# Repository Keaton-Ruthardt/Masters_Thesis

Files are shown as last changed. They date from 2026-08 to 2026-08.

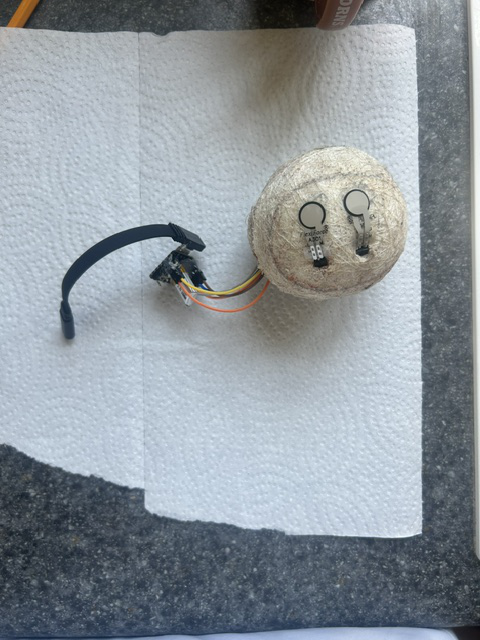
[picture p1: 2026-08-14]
figures/wiring+sensors-stripped-ball.jpeg

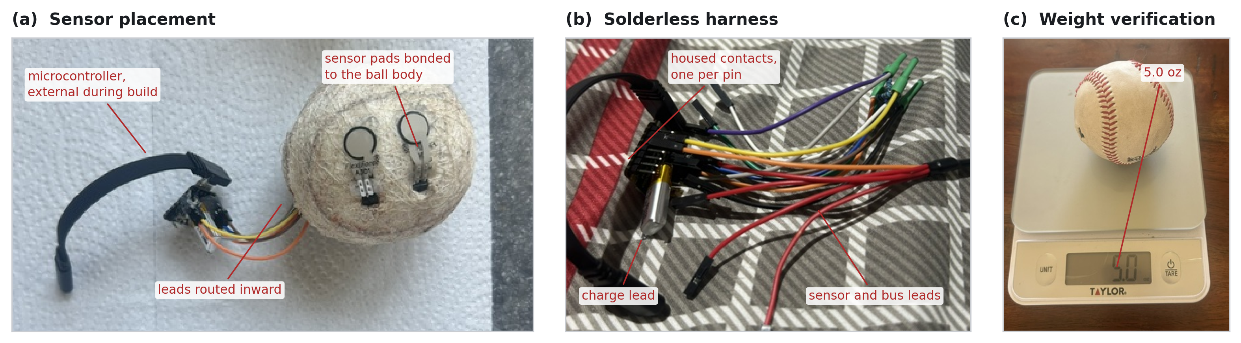
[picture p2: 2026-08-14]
figures/fig3_construction.png

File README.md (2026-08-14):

# An Instrumented Baseball for Per-Finger Grip Force Measurement

Reproducibility materials for the MS thesis *An Instrumented Baseball for Per-Finger
Grip Force Measurement: Finger Force Tracks Delivery Effort Rather Than Release Velocity*
(Keaton Ruthardt, MS Computer Science — Data Science, Oral Roberts University, 2026).

A regulation baseball instrumented with four thin-film force sensors under the leather
cover, sampling all channels at 480 Hz and streaming over Bluetooth Low Energy, paired
per pitch with TrackMan radar release velocity.

## What the study found

Measured the way the field currently measures it — with a graded submaximal effort
ladder — grip force predicts release velocity strongly and broadly: index + middle
force at release reaches *r* = 0.59, and 15 of 20 grip features remain significant
after Holm correction.

Holding commanded effort fixed removes that association. Index + middle force at
release falls to *r* = 0.33 (n.s.), and its unique contribution to velocity variance
is **ΔR² = 0.000**, against 0.743 for commanded effort alone. A mixed-effects model
agrees (χ²(1) = 0.47, *p* = 0.49).

Three thumb-dominated features survive Benjamini–Hochberg correction (*q* = 0.035);
none clears family-wise correction, and all are reported as **exploratory**.

The conclusion is that finger grip force, measured under a submaximal effort protocol,
is largely a readout of delivery effort rather than a determinant of release velocity.

## Layout

| Path | Contents |
|---|---|
| `thesis/` | The thesis (`MSCS_Paper.docx`) and its Quarto source, bibliography, and CSL style |
| `defense/` | Defense presentation, including a copy with speaker notes |
| `Masters_Thesis_and_Defense.zip` | Thesis and presentation bundled together |
| `firmware/` | Arduino sketches for the Seeed XIAO nRF52840 |
| `acquisition/` | `ble_logger.py` — BLE client, writes raw counts to CSV |
| `calibration/` | Per-sensor calibration procedure, fitting script, factors, raw captures |
| `analysis/` | Feature extraction, statistics, and figure generation |
| `analysis/results/` | Derived, de-identified data and generated statistical reports |
| `figures/` | Figures as they appear in the thesis |
| `hardware/` | KiCad PCB project, schematic and layout PDFs, bill of materials |
| `docs/` | Illustrated build guides, project plan, proposal |

### Firmware

- `pressure_logger_480/` — **deployed** acquisition firmware. 480 Hz, four samples per packet.
- `pressure_logger/` — earlier 120 Hz single-sample version; the host logger supports both.
- `isolation_test/` — channel-isolation gate.
- `sensor_test/`, `single_sensor/`, `calibrate_sensors/` — bench-check sketches.

Built with the Arduino IDE and the Seeed nRF52 **mbed-enabled** board package. The
non-mbed package fails to link.

## Wire protocol

The pressure characteristic carries a **36-byte packet**: a 32-bit unsigned microsecond
timestamp for the first sample in the batch, followed by four sample groups of four
16-bit unsigned ADC values each, little-endian, in channel order S1 through S4. Sample
*k* within a batch occurs at the batch timestamp plus *k* × 2083 µs.

The earlier firmware sends a 12-byte packet: a 32-bit millisecond timestamp followed by
four 16-bit ADC values. `ble_logger.py` derives the batch size from the packet length
and works against either version without modification.

## Data dictionary

Each logged CSV row contains:

| Column | Meaning |
|---|---|
| `wall_iso` | Host wall-clock time, ISO 8601, UTC |
| `wall_unix_ms` | Host wall-clock time, integer ms since the Unix epoch |
| `ball_t_ms` | The instrument's own timebase in ms — **the authoritative timing column** |
| `s1`–`s4` | Raw ADC counts, 0–4095, in channel order |
| `s1_N`–`s4_N` | Convenience force values in newtons |
| `marker` | Operator-typed per-pitch tag (pitch id, effort, outcome) |

Raw counts are the archived source of truth. Calibration is applied downstream in
analysis, never on the ball, so it can be revised without re-collecting data.

## Force conversion

For a sensor of resistance *R*ₛ in series with a fixed 10 kΩ resistor, the divider node
read by the 12-bit ADC gives a conductance ratio

```
G = ADC / (4095 - ADC)
F = c * G
```

where *c* is the per-sensor calibration factor in `calibration/calfactors_v3.csv`,
fitted through the origin by least squares over twenty applied-mass trials per sensor
(R² = 0.961 to 0.995).

## Reproducing the analysis

```bash
pip install numpy pandas scipy statsmodels matplotlib
cd analysis
python thesis_analysis_v2.py     # feature extraction -> results/
python advanced_stats.py         # corrections, variance decomposition, bootstrap
python make_thesis_figures.py    # figures
```

A fixed random seed (20260805) makes every reported *p*-value reproducible: 20,000
permutations and 10,000 bootstrap resamples throughout.

Note that `thesis_analysis_v2.py` reads raw session captures, which are not distributed
here (see below). The derived feature table it produces, `analysis/results/per_pitch_features.csv`,
**is** included, and `advanced_stats.py` and `make_thesis_figures.py` run from it directly.

## Participant data

Raw per-pitch session captures are **not included**, in accordance with the
participant-privacy commitments described in the thesis. Participants consented to their
data being used in the study; that consent did not extend to public redistribution of
raw records.

Derived, de-identified summary data sufficient to reproduce the reported figures and
models are provided in `analysis/results/`. Pitchers are identified only as P1, P2, P3.

## Licensing

- **Code and firmware** — [MIT License](LICENSE)
- **Documentation, figures, and build records** — [CC BY 4.0](LICENSE-DOCS)

Both are permissive and allow reuse with attribution, which is the intent for a
reproducibility release: you should be able to rebuild the instrument and re-run the
analysis without seeking further permission.

Third-party software is used in accordance with its own licenses, none of which impose
copyleft obligations on this project's code. TrackMan, PitchLogic, Kookaburra,
FlexiForce, Tekscan, Seeed, and Nordic Semiconductor are trademarks of their respective
owners, used nominatively to identify the products actually used or discussed. No
endorsement is implied.

## Safety

The instrument places a lithium-polymer cell and rigid electronics inside a ball thrown
at speed. If you rebuild it, read `docs/BALL_INTEGRATION_GUIDE.md` first. Epoxy is poured
in ~15 g layers with each cured before the next, because the exotherm of a single large
pour is a genuine thermal hazard to an enclosed LiPo cell, and the cell is wrapped before
potting. The ball is retired — not repaired — if the cover is breached, the potted block
loosens, the cell swells or fails to hold charge, or the channel-isolation test fails
after an impact. The cell cannot be removed once potted, so retirement means disposal of
the whole assembly through appropriate lithium-battery disposal.

## Citation

```bibtex
@mastersthesis{ruthardt2026instrumented,
  author = {Ruthardt, Keaton},
  title  = {An Instrumented Baseball for Per-Finger Grip Force Measurement:
            Finger Force Tracks Delivery Effort Rather Than Release Velocity},
  school = {Oral Roberts University},
  year   = {2026},
  type   = {MS thesis}
}
```

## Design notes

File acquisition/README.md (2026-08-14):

# SmartBall BLE Logger

Streams the XIAO nRF52840 SmartBall's 200 Hz grip-pressure notifications to a
timestamped CSV for post-processing against TrackMan.

Pairs with `firmware/pressure_logger/pressure_logger.ino`.

## Setup

```bash
pip install -r requirements.txt
```

## Run

Power the ball **on the LiPo** (not USB) so it advertises as `SmartBall`, then:

```bash
python ble_logger.py --out session_2026-07-11.csv
```

- Press **ENTER** between pitches to drop a marker row (type a label first, e.g.
  `fastball7`, then ENTER). Use these to align each pitch with its TrackMan row.
- **Ctrl+C** stops cleanly, flushes the file, and prints a summary
  (samples logged, estimated dropped packets, effective rate).

### Options

| Flag | Default | Purpose |
|---|---|---|
| `--out FILE` | `smartball_<timestamp>.csv` | output path |
| `--name NAME` | `SmartBall` | BLE local name to connect to |
| `--duration S` | run until Ctrl+C | auto-stop after S seconds |
| `--scan-timeout S` | `20` | scan timeout before giving up |
| `--no-force` | off | log raw ADC only (skip force columns) |
| `--quiet` | off | suppress the live readout |

## Output columns

`wall_iso, wall_unix_ms, ball_t_ms, idx, mid, thb, rng, idx_N, mid_N, thb_N, rng_N, marker`

- **`ball_t_ms`** — the ball's own `millis()` clock; use this for sample-to-sample
  timing and pitch segmentation.
- **`wall_*`** — laptop wall clock for coarse alignment to TrackMan session time.
- **`idx/mid/thb/rng`** — raw 12-bit ADC. **This is the source of truth.**
- **`*_N`** — convenience force estimate using the firmware conductance model
  (`G = adc/(4095-adc)`, `F = G·calFactor`). `thb`/`rng` calFactors are still
  placeholders (150) pending the S3/S4 calibration fits — re-derive force in
  analysis from raw ADC once those land.

## Notes

- Segment pitches by the grip build-up / release-dropout in the pressure signal,
  cross-checked against the ENTER markers.
- Dropped-packet estimate assumes 5 ms spacing (200 Hz); a `ball_t_ms` jump > 7 ms
  is counted as missed samples. Some loss is expected over BLE — the ball clock
  keeps analysis honest.

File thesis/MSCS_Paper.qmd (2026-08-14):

---
format:
  docx:
    reference-doc: "MSCS Paper Outline.docx"
    toc: false
    number-sections: false
bibliography: references.bib
# APA 7th edition, per reviewer recommendation. To enable: download
#   https://www.zotero.org/styles/apa
# save it as apa.csl beside this file, then uncomment the next line.
# Leaving it commented renders in Chicago author-date (pandoc's default).
csl: apa.csl
---

<!--
  MSCS Paper: Instrumented Baseball for Grip Pressure Analysis
  GCSC 599 — Oral Roberts University
  Author: Keaton Ruthardt

  RENDERING: Run `quarto render MSCS_Paper.qmd` to generate MSCS_Paper.docx

  PRE-SUBMISSION CHECKLIST (Word, after rendering):
  1. Center-align the Title Page and Committee Approval blocks (Ctrl+E)
  2. Right-click the Table of Contents -> Update Field (or Ctrl+A then F9 for all fields).
     Do the same for the List of Tables and List of Figures.
  3. Convert every "Table N." / "Figure N." label to a Word caption via
     References > Insert Caption, so numbering and the lists auto-update.
  4. Accept all tracked changes and turn Track Changes OFF. Remove all comments.
  5. Check page breaks: no heading orphaned at the foot of a page, no table or
     figure split from its caption.
  6. Verify the reference list is alphabetical with hanging indents.
  7. Human proofread. Spelling/grammar tools are a supplement, not a substitute.
-->

```{=openxml}
<w:p><w:pPr><w:jc w:val="center"/></w:pPr><w:r><w:rPr><w:b/></w:rPr><w:t>AN INSTRUMENTED BASEBALL FOR PER-FINGER GRIP FORCE MEASUREMENT: FINGER FORCE TRACKS DELIVERY EFFORT RATHER THAN RELEASE VELOCITY</w:t></w:r></w:p>
<w:p><w:pPr><w:jc w:val="center"/></w:pPr><w:r><w:t></w:t></w:r></w:p>
<w:p><w:pPr><w:jc w:val="center"/></w:pPr><w:r><w:t>A Project</w:t></w:r></w:p>
<w:p><w:pPr><w:jc w:val="center"/></w:pPr><w:r><w:t></w:t></w:r></w:p>
<w:p><w:pPr><w:jc w:val="center"/></w:pPr><w:r><w:t>Presented to</w:t></w:r></w:p>
<w:p><w:pPr><w:jc w:val="center"/></w:pPr><w:r><w:t></w:t></w:r></w:p>
<w:p><w:pPr><w:jc w:val="center"/></w:pPr><w:r><w:t>the Faculty of the Computing and Mathematics Department</w:t></w:r></w:p>
<w:p><w:pPr><w:jc w:val="center"/></w:pPr><w:r><w:t></w:t></w:r></w:p>
<w:p><w:pPr><w:jc w:val="center"/></w:pPr><w:r><w:t>Oral Roberts University</w:t></w:r></w:p>
<w:p><w:pPr><w:jc w:val="center"/></w:pPr><w:r><w:t></w:t></w:r></w:p>
<w:p><w:pPr><w:jc w:val="center"/></w:pPr><w:r><w:t>In partial fulfillment of the requirements for the degree of</w:t></w:r></w:p>
<w:p><w:pPr><w:jc w:val="center"/></w:pPr><w:r><w:t></w:t></w:r></w:p>
<w:p><w:pPr><w:jc w:val="center"/></w:pPr><w:r><w:t>Master of Science, Computer Science, Data Science</w:t></w:r></w:p>
<w:p><w:pPr><w:jc w:val="center"/></w:pPr><w:r><w:t></w:t></w:r></w:p>
<w:p><w:pPr><w:jc w:val="center"/></w:pPr><w:r><w:t>Prepared by</w:t></w:r></w:p>
<w:p><w:pPr><w:jc w:val="center"/></w:pPr><w:r><w:t></w:t></w:r></w:p>
<w:p><w:pPr><w:jc w:val="center"/></w:pPr><w:r><w:rPr><w:i/></w:rPr><w:t>Keaton Ruthardt</w:t></w:r></w:p>
<w:p><w:pPr><w:jc w:val="center"/></w:pPr><w:r><w:t></w:t></w:r></w:p>
<w:p><w:pPr><w:jc w:val="center"/></w:pPr><w:r><w:rPr><w:i/></w:rPr><w:t>August 2026</w:t></w:r></w:p>
<w:p><w:r><w:br w:type="page"/></w:r></w:p>
<w:p><w:pPr><w:jc w:val="center"/></w:pPr><w:r><w:rPr><w:b/></w:rPr><w:t>Committee Approval</w:t></w:r></w:p>
<w:p><w:pPr><w:jc w:val="center"/></w:pPr><w:r><w:t></w:t></w:r></w:p>
<w:p><w:pPr><w:jc w:val="center"/></w:pPr><w:r><w:t>This project report has been reviewed and unanimously approved by the Project Committee.</w:t></w:r></w:p>
<w:p><w:pPr><w:jc w:val="center"/></w:pPr><w:r><w:t></w:t></w:r></w:p>
<w:p><w:pPr><w:jc w:val="center"/></w:pPr><w:r><w:t>____________________________________     ______________________________</w:t></w:r></w:p>
<w:p><w:pPr><w:jc w:val="center"/></w:pPr><w:r><w:t>Dr. Woerner, Committee Chair                Signature and Date</w:t></w:r></w:p>
<w:p><w:pPr><w:jc w:val="center"/></w:pPr><w:r><w:t></w:t></w:r></w:p>
<w:p><w:pPr><w:jc w:val="center"/></w:pPr><w:r><w:t>____________________________________     ______________________________</w:t></w:r></w:p>
<w:p><w:pPr><w:jc w:val="center"/></w:pPr><w:r><w:t>Dr. Valderrama, Committee Member            Signature and Date</w:t></w:r></w:p>
<w:p><w:pPr><w:jc w:val="center"/></w:pPr><w:r><w:t></w:t></w:r></w:p>
<w:p><w:pPr><w:jc w:val="center"/></w:pPr><w:r><w:t>____________________________________     ______________________________</w:t></w:r></w:p>
<w:p><w:pPr><w:jc w:val="center"/></w:pPr><w:r><w:t>Wes Davis, Committee Member                 Signature and Date</w:t></w:r></w:p>
<w:p><w:r><w:br w:type="page"/></w:r></w:p>
```

```{=openxml}
<w:p>
  <w:pPr><w:jc w:val="center"/></w:pPr>
  <w:r>
    <w:rPr><w:b/></w:rPr>
    <w:t>Table of Contents</w:t>
  </w:r>
</w:p>
<w:p>
  <w:r>
    <w:fldChar w:fldCharType="begin" w:dirty="true"/>
  </w:r>
  <w:r>
    <w:instrText xml:space="preserve"> TOC \o "1-1" \h \z \u </w:instrText>
  </w:r>
  <w:r>
    <w:fldChar w:fldCharType="separate"/>
  </w:r>
  <w:r>
    <w:t>[Right-click and select Update Field to generate the Table of Contents]</w:t>
  </w:r>
  <w:r>
    <w:fldChar w:fldCharType="end"/>
  </w:r>
</w:p>
<w:p><w:r><w:br w:type="page"/></w:r></w:p>
<w:p><w:pPr><w:jc w:val="center"/></w:pPr><w:r><w:rPr><w:b/></w:rPr><w:t>List of Tables</w:t></w:r></w:p>
<w:p>
  <w:r><w:fldChar w:fldCharType="begin" w:dirty="true"/></w:r>
  <w:r><w:instrText xml:space="preserve"> TOC \h \z \t "Table Caption,1" </w:instrText></w:r>
  <w:r><w:fldChar w:fldCharType="separate"/></w:r>
  <w:r><w:t>[Right-click and select Update Field to generate the List of Tables]</w:t></w:r>
  <w:r><w:fldChar w:fldCharType="end"/></w:r>
</w:p>
<w:p><w:pPr><w:jc w:val="center"/></w:pPr><w:r><w:rPr><w:b/></w:rPr><w:t>List of Figures</w:t></w:r></w:p>
<w:p>
  <w:r><w:fldChar w:fldCharType="begin" w:dirty="true"/></w:r>
  <w:r><w:instrText xml:space="preserve"> TOC \h \z \t "Figure Caption,1" </w:instrText></w:r>
  <w:r><w:fldChar w:fldCharType="separate"/></w:r>
  <w:r><w:t>[Right-click and select Update Field to generate the List of Figures]</w:t></w:r>
  <w:r><w:fldChar w:fldCharType="end"/></w:r>
</w:p>
```

{{< pagebreak >}}

# PROJECT DESCRIPTION

This project presents the design and construction of an instrumented baseball that measures grip pressure distribution at the finger contact points during live pitching. The instrument embeds four thin-film force-sensitive resistors at the primary finger contact points (index, middle, thumb, and ring finger), sampled by a Bluetooth Low Energy 5 microcontroller (Seeed XIAO nRF52840) that streams the data wirelessly to a companion logger. Release velocity is captured concurrently by an Oral Roberts University TrackMan Doppler radar system, an established commercial pitch-tracking reference that has been reported as the ball-tracking component of Major League Baseball's Statcast system [@trackman; @statcast]. Each pitch therefore yields a paired record: how the ball was gripped, measured on-board, and what the ball did as a result, measured independently. Sourcing the ball-flight outcome externally rather than from on-board inertial sensors lets the instrument concentrate on the grip-pressure measurement it uniquely provides. The complete assembly preserves regulation weight and balance.

The specific contribution is the combined measurement system: per-pitch, per-finger grip behavior recorded through the release event, paired with independently measured ball-flight outcomes. Prior instrumented baseballs have measured either finger force or ball flight; the reviewed literature does not report a system that records both for the same pitch at four finger positions [@kinoshita2017; @yeh2024; @pitchlogic].

## Problem Statement

Pitch-tracking systems measure what the ball does after it leaves the pitcher's hand, and none of them measures the grip that produced it [@pitchlogic; @statcast]. Research instruments that do measure finger force during pitching exist, but they are laboratory devices that report force alone, and the most recent instrumented only the index and middle fingers [@kinoshita2017; @yeh2024]. A pitcher told to change how they hold the ball therefore has no way to verify that the change was executed, and no way to relate it to the result.

That is a measurement gap, and closing it is the primary engineering problem this project addresses. But there is a second problem, in the evidence rather than the instrumentation, and it turns out to govern what the measurement is worth.

Establishing that grip force relates to release velocity *within* a pitcher requires a spread of velocities to correlate against. A single pitcher's maximum-effort fastballs vary by little more than the resolution of the outcome instrument, so the standard solution is a graded submaximal effort protocol [@kinoshita2017]. Commanded effort, however, raises grip force and ball velocity together. A correlation obtained under that protocol is confounded by the very design that made it estimable, and it cannot by itself distinguish a genuine grip--outcome relationship from the trivial observation that harder throws involve harder gripping. Separating the two requires recording commanded effort for every pitch and holding it fixed in the analysis --- which in turn requires an instrument that captures per-finger grip force pitch by pitch, under live conditions rather than in a laboratory.

This project therefore addresses two coupled problems: it builds a self-contained instrumented baseball that records grip pressure at four finger positions during live pitching, pairs each pitch with an independently measured release velocity, and uses that pairing to test whether grip force carries velocity information that delivery effort does not.

## Scope and Deliverables

The project is organized into five phases:

1. **Proof of Concept** (Weeks 1--4): Breadboard prototype with pressure sensors, a development-grade IMU, and BLE data transmission to validate the core data pipeline.
2. **nRF52840 Migration and Four-Sensor Array** (Weeks 5--10): Migration from ESP32 to the nRF52840 microcontroller, the platform adopted by comparable commercial smart balls, expansion to four pressure sensors covering the primary finger positions, and firmware rewrite for BLE 5.
3. **Instrument Fabrication** (Weeks 11--16): Building a throwable, self-contained instrument around the Seeed XIAO nRF52840, a lithium-polymer battery, and the four-sensor array, with per-sensor force calibration. A custom rigid PCB was attempted during this phase; its fabrication outcome and the resulting build decision are documented in the milestones and change proposals.
4. **Baseball Integration** (Weeks 17--19): Embedding the electronics into a regulation baseball using a construction method informed by McGinnis (2012) and Yeh et al. (2024), routing sensor leads to the finger contact positions, and verifying weight, balance, and durability for live throwing.
5. **Data Collection and Analysis** (Weeks 20--26): Capturing paired grip-pressure and TrackMan ball-flight data across pitchers and pitch types, and developing a companion pipeline that extracts grip-force features and relates them to release velocity.

## Equipment and Facilities

**Fabrication and bench equipment.** Soldering station, digital multimeter, breadboards, and a crimping tool for the insulated ferrule and housed-contact terminations used in the second instrument. A digital scale reading to 0.1 g verifies regulation mass, and a flat roll surface checks balance.

**Deployed instrument.** Four FlexiForce A301 thin-film force sensors; a Seeed XIAO nRF52840 development board (Nordic Semiconductor nRF52840 with BLE 5); a 100 mAh lithium-polymer cell charged through the board's on-board charger via a USB-C pigtail; 10 k$\Omega$ divider resistors; two-part epoxy for potting; and a regulation baseball, deconstructed and re-stitched. The custom printed circuit board specified in the original plan was fabricated but non-functional, and the deployed instrument is built on the development board instead (CP-12).

**Calibration.** Per-sensor calibration was performed against a scale-referenced staircase of known masses applied through a rigid platen, twenty trials per sensor, with the fitted factors recorded in Table 1 and applied downstream in analysis rather than on the ball.

**Ball-flight reference.** Release velocity is obtained from the Oral Roberts University TrackMan Doppler radar, a stadium-grade commercial tracking system [@trackman; @statcast]. TrackMan also reports spin and movement, but Doppler tracking of the instrumented ball proved intermittent---the altered interior shortens the radar track---and those quantities were recovered for too few pitches to analyze. **Velocity is the only ball-flight outcome used in this work.**

**Facilities.** Data collection took place at the ORU TrackMan facility, throwing from a mound at regulation distance during ordinary training sessions.

**Software.** A companion Python logger built on the Bleak Bluetooth library records the wireless stream to timestamped CSV, with each pitch's outcome typed into a marker field at capture. Analysis is in Python (NumPy, pandas, SciPy, statsmodels, scikit-learn, Matplotlib).

Actual expenditure is reported per phase in the milestones rather than estimated here.

## Subject Matter Experts

The project committee consists of Dr. Woerner (Chair), Dr. Valderrama, and Wes Davis, who provide expertise in computer science, data science, and domain knowledge relevant to the project.

## Project Criteria

This project satisfies the criteria for a master's project as follows:

- **Independence.** The project is a discrete unit with a well-defined beginning (sensor validation) and end (a functioning instrumented baseball with analysis capability), with clearly defined success criteria at each phase.
- **Ownership.** The student is solely responsible for all hardware design, firmware development, integration, and analysis pipeline development.
- **Background Research.** The project requires investigation of prior instrumented ball designs, force-sensing technologies, embedded systems packaging constraints, and pitching biomechanics literature before and during implementation.
- **Creativity.** Within the products and literature reviewed for this project, no existing design combines multi-point grip-pressure sensing with a concurrent, independently measured ball-flight outcome in a single baseball-form-factor instrument. The solution requires integration of mechanical, electrical, and software engineering disciplines.

# MOTIVATION

Modern pitch-tracking technologies have advanced rapidly in quantifying ball-flight metrics. Products such as PitchLogic embed inertial sensors inside a regulation baseball to report velocity, spin rate, spin axis, and seam orientation in near-real-time [@pitchlogic]. Radar- and camera-based systems such as Rapsodo [@driveline2018], and stadium-level installations such as Statcast [@statcast], provide additional ball-flight data from external vantage points. However, all of these systems measure only what the ball does after it leaves the pitcher's hand; they capture no information about the grip forces that produced those outcomes.

This gap matters because recent biomechanics research demonstrates a direct link between finger forces and pitch quality. A 2024 study published in *Sensors* used a sensor-embedded baseball to examine finger characteristics in twenty-one pitchers and found significant correlations between finger force rate of development, impulse, and force discrepancy with both spin rate and pitching velocity [@yeh2024]. Earlier work by Kinoshita et al. established that the index and middle fingers each exert peak resultant forces of approximately 97 N during fastball delivery, and that the shear forces generated by these fingers at release---summing to 102 N---are the kinetic source of backspin [@kinoshita2017]. These studies provide evidence that grip force patterns are not merely incidental to pitching mechanics.

There is, however, a difficulty in that evidence that motivates the present work as much as the measurement gap does. Establishing a within-pitcher relationship between grip force and velocity requires a range of velocities to correlate against, and the standard way to induce that range is to have the pitcher throw at graded submaximal effort [@kinoshita2017]. But commanded effort raises grip force and ball velocity together, so a correlation obtained that way is confounded by the design that made it estimable. Distinguishing a grip--outcome relationship from the trivial observation that harder throws involve harder gripping requires recording commanded effort per pitch and holding it fixed---which requires, in turn, an instrument that captures grip force pitch by pitch under live conditions. That is the instrument this project builds, and the distinction turns out to matter a great deal.

Despite this evidence, no existing tool provides pitchers or coaches with objective, real-time feedback on grip pressure distribution during live throws. Training adjustments remain guided by subjective feel and verbal coaching cues. A pitcher who is told to "grip the ball tighter with the index finger" has no way to quantify that adjustment or verify that it was executed as intended. This leaves a critical performance variable unmeasured and unmanaged.

The instrumented baseball developed in this project addresses that gap. By embedding force-sensitive resistors at each finger contact point and pairing them with a concurrent, independently measured release velocity, the system produces a unified per-pitch dataset: how the ball was gripped and what the ball did as a result. This pairing supports a feedback loop that subjective coaching cues alone cannot provide.

The platform may also be relevant to training-load research. Pitching biomechanics research has quantified the substantial elbow and shoulder loads the throwing motion generates and connected them to injury mechanisms [@fleisig1995], and Kinoshita et al. observed that maximal-effort fastballs demand more than 80 percent of a pitcher's measured maximum finger strength, which the authors interpret as supporting a role for distal-finger conditioning [@kinoshita2017]. Whether measured finger-force patterns carry any predictive relationship to injury is beyond the scope and design of the present study, and no such claim is made here; the connection is identified only as a direction that a larger prospective study could investigate. The architecture is generalizable to other sports where grip is consequential and unmeasured, including cricket bowling, softball pitching, and football throwing.

# OBJECTIVES

The primary objective is to design and fabricate a throwable, self-contained instrumented baseball that captures real-time grip pressure distribution across four finger contact points (index, middle, thumb, and ring finger) during regulation pitching motions. The instrument embeds four thin-film force-sensitive resistors at the finger contact positions, samples all four channels continuously, and transmits the resulting data wirelessly via Bluetooth Low Energy 5 to a companion logger. The complete assembly maintains regulation weight and balance.

The secondary objective is to pair each pitch's grip-pressure record with independently measured ball-flight outcomes. Rather than estimating velocity and spin from on-board inertial sensors---an approach constrained by MEMS gyroscope saturation and by drift in the integration of accelerometer data---this project uses the Oral Roberts University TrackMan Doppler radar as the ball-flight reference, providing release velocity for every pitch it successfully tracks. Individual pitches are tagged during capture and joined to their TrackMan records, producing a unified per-pitch dataset. Release is delimited within the pressure signal itself by the characteristic build-up and drop-out of grip force.

A tertiary objective is to develop a companion data pipeline that ingests the paired datasets and extracts interpretable grip-force features---peak force, rate of force development, impulse, and inter-finger force balance---for each pitch, then relates those features to release velocity. The analysis focuses on two representative pitch types, the four-seam fastball and the curveball, which contrast a low-movement, high-velocity grip with a high-spin, breaking-ball grip. The pipeline includes pitch segmentation, calibrated force conversion, feature extraction, and exploratory statistical analysis in Python, with data exported in standard formats (CSV).

# BACKGROUND: PRIOR AND OTHER CURRENT WORK

The study of pitching biomechanics has a long history, but instrumented measurement of the finger-ball interface remains in its early stages. This section reviews the key prior work that informs the present project, spanning commercial products, academic research on instrumented baseballs, and biomechanical studies of finger forces during pitching.

## Commercial Products: PitchLogic

PitchLogic represents the current state of the art in consumer-grade instrumented baseballs. The product embeds an inertial measurement unit inside a regulation-weight baseball and uses Bluetooth Low Energy to transmit pitch data to a companion mobile application in less than 0.1 seconds after release [@pitchlogic]. Reported metrics include velocity, spin rate, spin axis, spin efficiency, seam orientation, and release point. Pitching-development facilities such as Driveline Baseball have evaluated smart-ball and pitch-tracking technologies for training feedback [@driveline2018]. PitchLogic demonstrates the viability of embedding electronics in a baseball while maintaining acceptable weight and balance, and it validates BLE as a practical wireless protocol for this application. However, PitchLogic measures only ball-flight dynamics; it includes no pressure sensors and provides no information about grip forces.

## Miniaturized IMU Design for Baseballs

McGinnis and Perkins developed a highly miniaturized wireless IMU specifically designed for embedding in pitched baseballs and softballs [@mcginnis2012]. Their work established several important design principles for instrumented balls. First, the electronics must be centered at the ball's center of mass to minimize perturbation of the ball's moments of inertia. Second, the total added mass must be minimized---their design targeted masses small enough to avoid detectable changes in ball dynamics. Third, the IMU must have sufficient gyroscope range and sampling rate to capture the high angular velocities encountered in pitching, where fastball spin rates typically range from roughly 1,800 to 2,800 RPM [@statcast]. Their validation work confirmed that a properly miniaturized and centered electronics package does not significantly alter the flight characteristics of the ball, providing a critical proof of concept for the present project's approach to embedding additional pressure-sensing hardware.

## Finger Forces in Pitching

Kinoshita et al. conducted a foundational study of finger forces during fastball pitching by installing a three-dimensional force transducer inside a baseball [@kinoshita2017]. Data collected from eleven pitchers revealed that the index and middle fingers exhibit a bimodal force pattern, with initial peaks at approximately 38--39 milliseconds before release and secondary peaks at 6--7 milliseconds before release, each reaching approximately 97 N. The ring finger and thumb produced single-peak forces of approximately 50 N and 83 N, respectively. The shear forces generated by the index and middle fingers formed distinct peaks at 4--5 milliseconds before release, summing to 102 N---identified as the primary kinetic source of backspin. An additional experiment with submaximal effort demonstrated a linear relationship between peak finger forces and ball velocity, and the peak forces during maximal-effort fastballs exceeded 80 percent of measured maximum finger strength, suggesting that distal finger strengthening is important for both performance enhancement and injury prevention.

## Sensor-Embedded Baseball for Finger Characteristics

Most recently, Yeh et al. designed a sensor-embedded baseball to investigate the relationship between finger characteristics and pitching performance [@yeh2024]. Their study of twenty-one pitchers measured finger length and strength alongside pitch metrics captured by the embedded sensors. They found significant correlations between finger force rate of development, impulse, and inter-finger force discrepancy with both spin rate and pitching velocity. This work is the closest precursor to the present project in that it combines force measurement with ball-embedded sensing, though it focused on static finger characteristics rather than dynamic, pitch-by-pitch pressure distribution mapping.

## Related Instrumented-Ball and Sensing Systems

Instrumenting sports balls with embedded electronics is an established line of work beyond baseball. Miniature wireless inertial units have characterized golf-swing dynamics [@king2008] and bowling-ball motion [@king2011], and smart cricket balls have been developed for detailed bowling performance analysis [@fuss2015; @fuss2021]. Distributed wearable sensor systems have likewise been applied to evaluating pitchers and batters [@paradiso2006], and the instrumented-baseball concept has been patented [@perkins_patent2015; @mcginnis_procedia2012]. The Nordic nRF52840 microcontroller used here is the same platform adopted by commercial smart balls, including the Kookaburra SmartBall [@nordic_smartball] and the PitchLogic baseball [@nordic_pitchlogic; @nordic_nrf52840], and independent validation of PitchLogic against reference instruments has been reported [@samford2020; @driveline2018]. On the sensing side, the FlexiForce A301 force-sensitive resistor is a widely used thin-film transducer whose conductance-versus-force behavior underlies the calibration model applied in this project [@tekscan_a301]. For ball-flight interpretation, spin and movement follow well-characterized baseball aerodynamics [@nathan_aero], and magnetometer-based spin measurement---the commercial basis for treating spin as an externally measured quantity---has been described in the patent literature [@diamondkinetics_spin].

## Synthesis

Collectively, these studies establish three key findings that motivate the present project: (1) finger forces are directly linked to pitch quality and can be measured with embedded sensors; (2) electronics can be embedded in a baseball without significantly altering its dynamics; and (3) no existing system provides per-pitch grip pressure distribution data paired with a concurrent ball-flight outcome. The present project addresses this gap by combining multi-point grip-pressure sensing with a concurrent, externally referenced release velocity in a single, wirelessly communicating instrument.

# REQUIREMENTS (project)

This section specifies the functional and non-functional requirements for the instrumented baseball system.

## Functional Requirements

The system shall:

1. **Measure grip pressure** at four discrete finger contact points (index, middle, thumb, and ring finger) using thin-film force-sensitive resistors [@tekscan_a301]. Each sensor resolves forces across the 0--25 pound (0--111 N) range with sufficient resolution to distinguish meaningful grip adjustments.

2. **Sample all four pressure channels** continuously at a fixed rate sufficient to resolve the release transient, time-stamped on-board so that grip build-up, peak, and release are temporally resolved within each pitch. The reference literature places the second pre-release force peak 6 to 7 ms before release [@kinoshita2017] and samples at 433 Hz [@yeh2024], establishing a target of at least 400 Hz. The deployed instrument samples at 480 Hz.

3. **Transmit data wirelessly** via Bluetooth Low Energy 5 to a companion logging device, which records the stream to timestamped CSV for post-processing.

4. **Support per-pitch tagging** during capture so that each grip-pressure record can be joined to its corresponding TrackMan ball-flight record.

5. **Delimit release** from the pressure signal itself: grip force builds during the arm action and drops out at ball release, marking the release point and bounding each pitch for feature extraction. Because the channels lose contact at different instants, release is resolved per finger rather than as a single ball-level event.

6. **Maintain channel independence.** Each pressure channel shall respond only to force applied at its own sensor. Cross-channel response shall remain below 5 percent of the driven channel, verified by instrumented test before and after each stage of assembly.

7. **Recharge via a wired USB-C connection.** No exposed high-voltage ports are present on the ball's surface during throwing, and the charge port is reachable for recharging and for firmware updates without disassembling the ball.

## Non-Functional Requirements

1. **Weight.** The total mass of the instrumented baseball shall not exceed 5.25 ounces (148.8 g), the upper bound of the regulation baseball weight of 5 to 5.25 ounces [@mlb_rules]. The added electronics mass shall be below 12 g, with a design target below 8 g.

2. **Balance.** The center of mass of the instrumented baseball shall not deviate perceptibly from that of a standard baseball. All electronics shall be centered at or near the geometric center of the ball.

3. **Sensor profile.** Pressure sensors mounted along the seams shall not exceed 0.5 mm in thickness to avoid perceptible alteration of the ball's grip surface.

4. **Durability.** The system shall withstand repeated pitching at velocities of 80+ mph without sensor or electronics failure. The design shall include potting and structural protection for internal components. *Met:* the deployed instrument was thrown at up to 82.4 mph across three sessions without sensor or electronics failure, streaming continuously and passing the channel-isolation check after use.

5. **Battery life.** The system shall operate on a single charge for the duration of a full data-collection session (several hours). Measured runtime is approximately eight hours on a 100 mAh, 3.7 V cell.

6. **Sampling fidelity.** Analog-to-digital conversion shall provide at least 12-bit resolution across all pressure channels.

7. **Latency.** Grip-pressure samples shall stream continuously to the receiving device in near-real-time over BLE, with the ball's own timestamp on each sample so that timing is preserved even when individual packets are dropped.

# DESIGN SPECIFICATION (project)

This section describes the system architecture, component selection rationale, data flow, power system design, and sensor placement strategy for the instrumented baseball.

## System Architecture

The instrumented baseball comprises three subsystems: (1) a four-channel grip-pressure sensor array, (2) a microcontroller with BLE 5 wireless communication, and (3) a rechargeable power system. Ball-flight metrics are supplied externally by the TrackMan Doppler radar rather than sensed on-board, which removes the inertial-measurement subsystem from the deployed instrument and focuses it on the grip-pressure measurement it is uniquely able to provide. Figure 1 shows the complete signal path.

Block diagram of the instrumented baseball system. On the ball: four FlexiForce A301 sensors feed voltage dividers, sampled by a XIAO nRF52840 at 480 Hz, powered by a 100 mAh cell. Off the ball: a Bluetooth Low Energy link carries raw counts to a Python logger, and TrackMan radar supplies release v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

::: {custom-style="Figure Caption"}
Figure 1. *Instrumented baseball system architecture.* Force applied at each of four finger positions changes the resistance of a thin-film sensor; each sensor forms a voltage divider with a fixed 10 k$\Omega$ resistor, and the divider nodes are sampled by the microcontroller's 12-bit converter at 480 Hz. Samples are buffered, batched four to a packet, and transmitted over Bluetooth Low Energy to a Python logger that writes raw counts to CSV. Release velocity is measured independently and joined to the pressure record by a per-pitch tag. Note that calibration is applied downstream in analysis, not on the ball, so raw counts remain the archived source of truth.
:::

## Pressure Sensor Array

The pressure sensor array consists of four FlexiForce A301 thin-film force-sensitive resistors manufactured by Tekscan [@tekscan_a301]. These sensors are the same transducer family used by Yeh et al. in the closest precursor work, which employed the compact A301 variant of the same 0--111 N sensor [@yeh2024]. These sensors were selected for their ultra-thin polyester construction (0.2 mm thickness), small sensing area (9.5 mm diameter), and measurement range of 0--25 pounds (0--111 N), which encompasses the expected finger forces during pitching [@kinoshita2017]. The sensors are positioned at four finger contact points: one each for the index finger, middle finger, thumb, and ring finger. This configuration samples grip force at four discrete locations rather than mapping a continuous pressure distribution, and it extends the coverage of the closest prior work: Yeh et al. instrumented only the index and middle fingers, reporting no thumb or ring-finger data [@yeh2024]. Following the Yeh et al. construction method, the sensors are placed beneath the leather cover, where the leather transmits finger force to the 0.2 mm sensor while preserving natural grip feel. Figure 3 shows the sensor placement and internal construction.

## Ball-Flight Reference (TrackMan)

Ball flight is not sensed on-board. **Release velocity is the outcome measure of this work**, and it is obtained from the Oral Roberts University TrackMan Doppler radar, a stadium-grade commercial tracking system reported as the ball-tracking component of MLB Statcast [@trackman; @statcast; @nathan_aero]. TrackMan also reports spin rate, spin axis, and movement, and those quantities were recorded wherever the system returned them; in practice the instrumented ball's altered interior produced a shortened, intermittent radar track and they were recovered for too few pitches to support inference. They are reported descriptively where present and enter no model. Every outcome analysis in this document is against velocity. This choice avoids two well-documented limitations of ball-embedded inertial sensing. First, MEMS gyroscopes typically saturate near ±4,000 degrees per second [@st_ism330dhcx]---approximately 666 RPM on a single axis---far below the 1,800 to 2,800 RPM of a competitive fastball [@statcast], so a gyroscope cannot measure real pitch spin without saturating. Second, velocity estimates obtained by integrating accelerometer data accumulate drift. Using TrackMan as the ball-flight reference yields more accurate outcome measurements than an on-board IMU could provide, and lets the instrument devote its entire mass and power budget to grip-pressure sensing.

## Signal Conditioning

The pressure sensors are conductive-polymer force-sensitive resistors whose resistance falls (conductance rises) approximately linearly with applied normal force [@tekscan_a301]. Each sensor forms a voltage divider with a fixed 10 k$\Omega$ resistor, and the four divider nodes connect directly to analog inputs A0 through A3 of the XIAO nRF52840; no multiplexer is required.

For a sensor of resistance $R_s$ in series with the fixed resistor $R_f$, the divider node sampled by the 12-bit analog-to-digital converter reads

$$ \mathrm{ADC} = (2^{12}-1)\,\frac{R_f}{R_s + R_f}, \tag{1} $$

so that the dimensionless ratio

$$ G = \frac{\mathrm{ADC}}{4095 - \mathrm{ADC}} = \frac{R_f}{R_s} \tag{2} $$

is proportional to sensor conductance $1/R_s$. Because conductance is approximately proportional to applied force, force is recovered as

$$ F = c\,G = c\,\frac{\mathrm{ADC}}{4095 - \mathrm{ADC}}. \tag{3} $$

The symbols are defined as follows. $F$ is the applied normal force in newtons (N). $\mathrm{ADC}$ is the raw converter output, a dimensionless integer in the range 0 to 4095 at 12-bit resolution. $R_s$ is the sensor resistance in ohms ($\Omega$), which decreases with applied force. $R_f$ is the fixed divider resistance, 10 k$\Omega$ ($\pm$1 percent, metal film). $G$ is the dimensionless conductance ratio defined in Equation (2). The coefficient $c$ is the per-sensor calibration factor, in newtons per unit conductance ratio (N), determined empirically by the least-squares procedure described in *Sensor Calibration*; it is denoted `calFactor` in the firmware and analysis code.

Equation (3) is fit through the origin, on the physical grounds that zero applied force produces zero conductance. Raw $\mathrm{ADC}$ values are transmitted rather than converted force, so calibration is applied in post-processing and can be revised without re-collecting data. Two additional analog pins (A4, A5) remain unpopulated and available for future sensor expansion.

## Microcontroller and Wireless Communication

The Nordic Semiconductor nRF52840 serves as the central processing unit. This microcontroller was selected because it is the platform used by the closest commercial comparators: PitchLogic reports using the nRF52840 in its smart baseball [@nordic_pitchlogic], and the Kookaburra SmartBall uses it in its cricket ball [@nordic_smartball]. Adopting the same platform reduces technical risk, since the part is demonstrably capable of operating inside a thrown ball. Key specifications include a 64 MHz ARM Cortex-M4F processor with hardware floating-point unit, 256 KB SRAM, 1 MB flash, integrated BLE 5 radio (2 Mbps throughput), six analog input channels, and ultra-low-power sleep modes drawing less than 1 µA in system-off mode [@nordic_nrf52840].

The deployed instrument uses the Seeed XIAO nRF52840 development board (21 x 17 mm, \$10), which provides Arduino-compatible programming and USB-C connectivity in a package small enough to embed.

**Sampling rate and the acquisition/transmission decoupling.** The Bluetooth Low Energy link, not the sensor or the converter, sets the achievable sampling rate. A bench measurement established a ceiling near 151 Hz when 200 Hz was requested, because the link delivers approximately one notification per connection event. An initial firmware version therefore sampled at 120 Hz and transmitted one sample per notification in a 12-byte packet (a 32-bit millisecond timestamp followed by four 16-bit ADC values).

That rate proved adequate for the grip build-up and peak, which develop over roughly 100 ms, but marginal for the release transient. Pilot captures showed the entire release transition spanned only three to four samples at 120 Hz, which is insufficient to resolve either the rate of force development or the order in which individual fingers lose contact. Because the constraint is the notification rate rather than the sampling rate, the two were decoupled: the deployed firmware samples all four channels at **480 Hz** into a buffer and transmits four samples per notification in a 36-byte packet, holding the notification rate at 120 s⁻¹ and leaving the measured link ceiling untouched. Each packet carries a 32-bit microsecond timestamp for the first sample in the batch; the remaining sample times follow from the fixed 2.083 ms interval.

The microsecond timebase is a deliberate correction. An earlier batched version stamped each packet with a millisecond-resolution clock, which quantized an 8.33 ms batch to 1 ms and produced reconstructed sample times that overlapped across batch boundaries---measured at 2.9 percent of samples regressing by up to 4.25 ms, comparable in magnitude to the inter-finger release intervals being measured. Substituting the microsecond clock eliminated the effect; the verification capture reported zero non-monotonic samples across 21,140 records.

The resulting rate resolves the features the reference literature describes. Kinoshita et al. report bimodal index and middle finger peaks separated by roughly 30 ms, with the second peak 6 to 7 ms before release [@kinoshita2017]; Yeh et al. sampled at 433 Hz [@yeh2024]. At 480 Hz a sample arrives every 2.083 ms, placing approximately twelve samples across the release transition and making the second pre-release peak resolvable.

## Power System

The power system consists of a 100 mAh lithium-polymer battery (3.7 V nominal) charged through the XIAO's on-board charge controller over USB-C. The ball runs on the battery during throwing, which gives it a floating ground and low noise. Measured runtime is approximately eight hours on a full charge---comfortably longer than a full data-collection session (stitching, transport, and throwing). The charge port is exposed through a small window in the leather cover so the sealed ball can be recharged without disassembly.

## Wireless Data Acquisition

A companion Python logger, built on the Bleak Bluetooth library, scans for the instrument, subscribes to the pressure notify characteristic, and writes every sample to a timestamped CSV. Raw ADC is logged as the source of truth. During capture the operator tags each pitch with a unique identifier recorded inline in the log, so that grip records can later be joined to their TrackMan counterparts. Because each packet carries the ball's own millisecond timestamp, an occasional dropped BLE packet widens the sample interval without corrupting timing; all downstream feature computation uses the actual per-sample interval rather than an assumed period.

## Sensor Calibration

**Procedure.** Each sensor was calibrated against a digital scale (1 g resolution) used as the force reference. Calibrated masses were applied to the sensing pad through a rigid flat platen in a monotonically increasing staircase, each level held for approximately five seconds before the next mass was added. The mass sequence was 300, 600, 900, 1200, 1500, 2000, and 2900 g, corresponding to 2.94, 5.89, 8.83, 11.77, 14.72, 19.62, and 28.45 N at $g = 9.81$ m·s⁻². Sensors S1 and S2 were characterized over the full seven-level sequence to 28.45 N. Sensors S3 and S4 were characterized over the first six levels, to 19.62 N; a single seven-level trial was recorded for each but was not sufficient to revise their fitted factors, so their calibrated ceiling is reported as 19.62 N and the asymmetry is carried into the limitations. Each sensor was read through the same analog channel and the same fixed 10 k$\Omega$ divider used in the deployed instrument, so that calibration and measurement share their signal conditioning.

**Number of trials.** Twenty complete staircase trials were recorded per sensor. An earlier calibration, reported in intermediate project documentation, used four trials per sensor over a six-level sequence reaching 2000 g (19.62 N); those results are superseded by the twenty-trial protocol described here, and the figures below are the final values.

**Fitting.** Within each trial, the loaded samples were partitioned into levels by one-dimensional $k$-means clustering with $k$ equal to the number of applied masses, and each level was summarized by its median ADC value. This replaces an earlier threshold-and-jump segmentation heuristic that proved sensitive to the loading transient at the start of each staircase. The calibration factor $c$ of Equation (3) was then fit through the origin by least squares over the pooled level medians. A separate factor was fit within each trial to quantify repeatability as the coefficient of variation across trials.

**Results.** Table 1 reports the per-sensor calibration factors, coefficients of determination, and repeatability; Figure 2 shows the fitted curves.

Four scatter plots, one per sensor, of applied force in newtons against conductance ratio, each with a fitted line through the origin, its equation, coefficient of determination, root-mean-square error, trial count, and a dashed rule marking the calibrated ceiling.

::: {custom-style="Figure Caption"}
Figure 2. *Sensor calibration curves for the four deployed FlexiForce A301 sensors.* Applied force in newtons against the conductance ratio $G$ of Equation (2), with the fitted line through the origin for each sensor. Points are level medians pooled across twenty staircase trials per sensor. The reader should observe that all four sensors are well described by a single-parameter proportional model over the calibrated range, that they differ from one another in slope by up to a factor of 1.3---which is why per-sensor calibration is necessary---and that the calibrated range terminates at 28.45 N for two sensors and 19.62 N for the other two, above which the fitted relationship is extrapolated.
:::

::: {custom-style="Table Caption"}
Table 1. *Sensor calibration and repeatability results.* Calibration factor $c$ is the fitted coefficient of Equation (3), in newtons per unit conductance ratio. $R^2$ is computed on the pooled level medians across all trials. Repeatability is the coefficient of variation of the per-trial factor. The calibrated ceiling is the largest force applied during calibration; forces above it are extrapolated. Sensor S5 was characterized but withheld from the instrument.
:::

| Sensor | Channel | Fastball position | $c$ (N) | $R^2$ | Repeatability CV | Trials | Calibrated ceiling |
|:---|:---|:---|---:|---:|---:|---:|---:|
| S1 | A0 | Index  | 119 | 0.986 | 2.6 % | 20 | 28.45 N |
| S2 | A1 | Middle | 129 | 0.977 | 6.5 % | 20 | 28.45 N |
| S3 | A2 | Thumb  | 148 | 0.995 | 1.3 % | 20 | 19.62 N |
| S4 | A3 | Ring | 157 | 0.961 | 7.8 % | 20 | 19.62 N |
| S5 | --- | (withheld) | 331 | 0.973 | 7.1 % | 4 | 19.62 N |

A larger calibration factor indicates a less sensitive sensor: more force is required to produce the same conductance. Sensor S5 required approximately 2.8 times the force of S1 for equivalent output and was withheld from the instrument on that basis, retained only as a spare. The four deployed sensors span a factor of 1.3 between the most and least sensitive, which per-sensor calibration accounts for. Because the fastball and curveball grips place different fingers on different sensors, the "fastball position" column identifies the finger for that grip only; the full per-grip mapping is given in Table 3.

**Repeatability and its interpretation.** The trial-to-trial spread reflects the contact and seating consistency inherent to manually loading thin-film force-sensitive resistors, a documented characteristic of the sensor family [@tekscan_a301]. It is reported as a repeatability figure rather than treated as measurement error. A separate observation bears on interpretation: refitting two sensors from independent calibration sessions produced factors differing by approximately 20 percent from the earlier session. Session-to-session variability of this magnitude is consistent with the sensor family's documented sensitivity to load application and mounting, and it is the principal reason the analysis in this report emphasizes force *ratios* between fingers over absolute force values.

## Feature Extraction

For each segmented pitch, the analysis pipeline computes interpretable grip-force features per finger and in aggregate. Table 2 gives the full set with computational definitions. They fall into three groups.

*Magnitude features* --- peak force, impulse (the time integral of force over the pitch), and inter-finger force balance (each finger's share of total force at the peak instant, and the coefficient of variation across fingers).

*Rate features* --- rate of force development, defined as the maximum time derivative of force during build-up, and time to peak.

*Release-phase features* --- force at release, release time, and inter-finger release order. Force at the instant of release is zero by definition, so *force at release* is operationalized as the mean force over the final 10 ms before contact is lost, where contact is considered lost when a channel falls below 10 percent of its own peak for that pitch. *Release time* is the instant of that crossing, and *release order* is the ranking of release times across fingers.

The release-phase group is the reason for the 480 Hz sampling rate. These features are the ones most directly tied to the mechanics of ball departure, and they are not computable at rates that span the release transition in only a few samples. A resolution floor applies to release ordering: intervals shorter than two sample periods (4.17 ms at 480 Hz) are not resolvable within a single pitch and are reported only in aggregate across pitches.

::: {custom-style="Table Caption"}
Table 2. *Grip-force feature definitions and computational formulas.* For a single pitch, $F_i(t)$ denotes the calibrated force at finger $i$ in newtons, obtained from raw counts by Equation (3). $t_p$ is the pitch window and $P_i = \max_t F_i(t)$ is that finger's peak. Release is defined per finger as the last instant at which $F_i$ exceeds $0.10\,P_i$ after the peak.
:::

| Feature | Symbol | Definition | Unit |
|:---|:---|:---|:-----|
| Peak force | $P_i$ | $\max_t F_i(t)$ over the pitch window | N |
| Time to peak | $t_{p,i}$ | $\arg\max_t F_i(t)$, referenced to pitch onset | ms |
| Rate of force development | $\mathrm{RFD}_i$ | $\max_t \mathrm{d}F_i/\mathrm{d}t$ during build-up | N·s⁻¹ |
| Impulse | $J_i$ | $\int_{t_p} F_i(t)\,\mathrm{d}t$ | N·s |
| Release time | $t_{r,i}$ | last $t$ with $F_i(t) > 0.10\,P_i$ after peak | ms |
| Force at release | $F_{r,i}$ | mean $F_i$ over $[t_{r,i}-10\ \mathrm{ms},\ t_{r,i}]$ | N |
| Release lead | $\Delta t_{ij}$ | $t_{r,j} - t_{r,i}$ for finger pair $(i,j)$ | ms |
| Force share | $s_i$ | $P_i / \sum_j P_j$ at the peak instant | --- |
| Inter-finger discrepancy | $\mathrm{CV}_P$ | $\mathrm{SD}(P_i)/\mathrm{mean}(P_i)$ across fingers | --- |

Force at release, release lead, and inter-finger discrepancy are the features of primary interest. Peak force and impulse are reported for comparability with the reference literature [@kinoshita2017; @yeh2024], but the release-phase measures are more closely tied to the instant at which the ball actually departs the hand.

## Data Collection Protocol

Paired data are collected at the Oral Roberts University TrackMan facility. Pitchers throw two pitch types---the four-seam fastball and the curveball---while the ball streams grip pressure to the logger and the external reference records ball flight. Pitch boundaries within the continuous pressure stream are located from the grip build-up and release drop-out.

**Sensor-to-finger mapping.** The sensors occupy fixed positions on the ball, so which finger contacts which sensor depends on how the hand is oriented for each grip. Table 3 gives the mapping. The ring finger is not instrumented in the deployed configuration; three fingers are measured per grip.

::: {custom-style="Table Caption"}
Table 3. *Sensor-to-finger mapping by pitch type.* Sensor positions are fixed on the ball; the grip determines which finger contacts each sensor. Because a given finger is read by different sensors on different pitch types, absolute forces are not directly comparable across pitch types, and within-pitch-type force ratios are the preferred comparison.
:::

| Sensor | Channel | Four-seam fastball | Curveball / slider |
|:---|:---|:---|:---|
| S1 | A0 | Index  | Thumb  |
| S2 | A1 | Middle | (not contacted) |
| S3 | A2 | Thumb  | Index  |
| S4 | A3 | (not contacted) | Middle |

**Pitch tagging and record joining.** Each pitch is tagged during capture with an identifier typed into the logger and written inline to the pressure log. Where the external reference reports a per-pitch velocity, that value is entered into the same tag, so the outcome measure is embedded in the pressure record itself rather than joined afterward by sequence position. This design decision follows directly from an observed failure mode: during instrument shakedown the Doppler radar registered only one of five thrown pitches. Joining records by order under those conditions would have silently paired each grip record with the wrong outcome while producing a dataset with no visible defect. Pitches for which no outcome was captured are tagged explicitly as unpaired and excluded from outcome analyses rather than shifting the sequence.

## Mechanical Integration

The mechanical integration follows an approach informed by McGinnis and Perkins [@mcginnis2012] and Yeh et al. [@yeh2024]. A regulation baseball is opened along one figure-eight seam, and wound yarn and the cork-and-rubber pill are partially removed to create a central cavity sized for the XIAO nRF52840, the lithium-polymer cell, and the wiring harness. The four FlexiForce sensors are mounted under the leather cover at the mapped finger contact points, following Yeh et al.'s method: the 0.2 mm leather-covered sensor transmits finger force while preserving natural grip feel and protecting the sensor from abrasion. Contact points are marked on the outer cover as registration marks so that finger placement is repeatable between pitches and between pitchers, a control Yeh et al. identify as necessary given the 9.5 mm sensing area. Figure 3 shows the construction and sensor placement.

Three photographs of the instrumented baseball build: the ball with its cover removed showing sensor pads bonded to the wound yarn, the completed solderless harness, and the finished ball on a digital scale.

::: {custom-style="Figure Caption"}
Figure 3. *Instrumented baseball construction, harness, and weight verification.* Panel (a): the ball body with its leather cover removed, showing two of the four FlexiForce pads bonded to the wound yarn at marked finger contact points, with leads routed inward and the microcontroller held outside the ball during assembly. The cover is subsequently fitted over the pads, so that in use each pad lies between the finger and the leather rather than on the ball's surface. Panel (b): the completed solderless harness, in which every connection to the microcontroller is an insulated housed contact rather than a soldered joint. Panel (c): the finished ball on a digital scale.
:::

The reader should observe three things. First, the sensing pads sit on the ball body and are covered by leather, so the measured quantity is finger force transmitted through the cover rather than direct contact pressure. Second, no bare conductor is present at the microcontroller in panel (b); this is the construction change that resolved the channel-coupling failure described in the milestones, and it is shown schematically in Figure 5. Third, the finished mass reads 5.0 oz, at the lower bound of the regulation 5.0 to 5.25 oz range; note that this scale resolves to 0.1 oz, which is 40 percent of the entire regulation tolerance band, so it confirms the ball is approximately regulation but is too coarse to place it precisely within the range. No personally identifying information appears in any build photograph.

**Interconnect.** The harness is the element of the build that was redesigned between instrument versions, for reasons documented in the milestones. Every connection is made either by a crimped ferrule or by a factory-terminated housed contact; the harness contains no soldered joints. Each of the six connections---the 3.3 V bus, the ground bus, and four sensor nodes---is formed by inserting the participating conductors into a single insulated ferrule and crimping once. Each node joins three conductors: the sensor signal lead, the corresponding divider resistor's upper leg, and a lead terminating in a housed contact that plugs onto the analog pin. The ground bus gathers the four resistors' lower legs with a lead to the ground pin. Every ferrule barrel and every resistor body is individually sleeved in heat-shrink tubing, leaving no exposed conductor anywhere in the assembly.

This construction removes bare conductors and flux residue from the microcontroller's pin row, which is where the earlier instrument's channels failed. Channel independence is not assumed from the geometry; it is verified by instrumented test at each assembly stage, as described in the milestones.

**Potting and mass.** The electronics are centered at the ball's center of mass and potted in two-part epoxy for shock protection---Yeh et al. demonstrated that epoxy encapsulation survives impacts at 100 km·h⁻¹ against a wall. Epoxy is poured in layers of approximately 15 g, each cured before the next, because the exotherm of a single large pour presents a thermal hazard to the enclosed lithium-polymer cell; the cell is additionally wrapped before potting so that the epoxy does not bond directly to the pouch. The sensing pads and the USB-C charge lead are kept clear of epoxy. Yarn is repacked and ballast added to reach the regulation range of 142 to 149 g (5.0 to 5.25 oz) [@mlb_rules], with ballast placed opposite the charge lead so the center of mass remains centered; balance is confirmed by a roll test. The leather cover is then re-fitted and re-stitched.

# WORK BREAKDOWN STRUCTURE --- GANTT CHART

The project is organized into five sequential phases with a total estimated duration of twenty-six weeks. Each phase depends on successful completion of the preceding phase, managing technical risk by confirming feasibility at each step before proceeding.

## Phase Summary

Table 4 summarizes the five phases. Each phase gates the next, so that feasibility is confirmed before the following phase's cost is committed. Table 4 states the plan as approved; the milestones section reports what was actually completed and where the plan changed.

::: {custom-style="Table Caption"}
Table 4. *Project phases, durations, and deliverables.* Phases are sequential; each depends on the completion of its predecessor.
:::

| Phase | Duration | Weeks | Deliverable |
|:---|:---|:---|:---|
| 1. Proof of Concept | 4 weeks | 1--4 | Working breadboard prototype with BLE data streaming |
| 2. nRF52840 Migration + 4-Sensor Array | 6 weeks | 5--10 | 4-sensor prototype on XIAO nRF52840 with BLE |
| 3. Instrument Fabrication | 6 weeks | 11--16 | Throwable XIAO-based instrument with calibrated four-sensor array |
| 4. Baseball Integration | 3 weeks | 17--19 | Functional instrumented baseball |
| 5. Software and Analysis | 7 weeks | 20--26 | Complete system with analysis and thesis documentation |

## Detailed Activities by Phase

**Phase 1: Proof of Concept (Weeks 1--4).** Ordered initial components (DFRobot Beetle ESP32, two FlexiForce A301 sensors, MPU-6050 breakout). Built breadboard prototype. Wrote firmware to read pressure sensors and IMU data. Tested BLE data transmission to smartphone via nRF Connect. Validated pressure readings against known weights. Documented baseline sensor characteristics. Actual cost: \$104.

**Phase 2: nRF52840 Migration + 4-Sensor Array (Weeks 5--10).** Migrate from the ESP32 to the Seeed XIAO nRF52840 development board. Install Seeed nRF52840 board support in Arduino IDE. Wire four FlexiForce A301 sensors to analog pins A0 through A3 with 10 kΩ voltage dividers. Port BLE firmware from ESP32 BLE library to ArduinoBLE (nRF52840). Use ink/chalk method to map finger contact points for four-seam, two-seam, changeup, and curveball grips. Calibrate sensors with known weights. Estimated cost: \$60 (XIAO nRF52840 plus two additional FlexiForce sensors).

**Phase 3: Instrument Fabrication (Weeks 11--16).** Build the throwable, self-contained instrument around the Seeed XIAO nRF52840, a 100 mAh lithium-polymer battery, and the four-sensor array on a compact wiring hub. Finalize the 120 Hz BLE 5 streaming firmware and the companion Python logger. Calibrate each FlexiForce sensor against a known-force reference and record per-sensor calibration factors. Verify battery runtime and confirm the electronics package meets the added-mass target for baseball embedding. Estimated cost: minimal (components already purchased).

**Phase 4: Baseball Integration (Weeks 17--19).** Follow the hybrid McGinnis/Yeh construction method: unstitch half the leather cover, cut cork-rubber core, machine cavity for electronics, coat PCB and battery assembly in epoxy, position at center of mass, mount FlexiForce sensors under leather at mapped contact points, route 30 AWG wires through yarn channels, re-wind yarn for mass compensation, seal with styrene-acrylic polymer adhesive, and re-stitch leather. Verify final weight is within the regulation 142 to 149 gram range. Conduct throw tests to verify feel and flight characteristics. Estimated cost: minimal (components already purchased).

**Phase 5: Software and Analysis (Weeks 20--26).** Develop Python data analysis pipeline. Implement pitch segmentation using grip-force build-up and release drop-out. Apply per-sensor calibration and extract grip-force features (peak force, rate of force development, impulse, inter-finger balance) for each pitch. Join each grip record to its TrackMan record and build correlation analysis between grip-pressure features and TrackMan release velocity. Test with multiple pitchers across multiple pitch types. Write thesis content and document findings. Estimated cost: minimal (software-only phase).

## Timeline

Figure 4 shows the phase schedule. The critical path runs through instrument fabrication: the analysis phase cannot begin until a working instrument exists, which is why the fabrication setback documented in the milestones consumed schedule margin that had been reserved for analysis.

Gantt chart of five sequential project phases plotted against project week, with phase three, instrument fabrication, highlighted as the critical path.

::: {custom-style="Figure Caption"}
Figure 4. *Project timeline and Gantt chart.* Bars mark the weeks allocated to each phase. Phases do not overlap, so any slip in an earlier phase displaces all later phases.
:::

# APPROVED CHANGE PROPOSALS

The following change proposals were adopted during project implementation. Each records a deviation from the approved plan, the evidence that prompted it, and its consequence for the deliverable.

**CP-1: Initial Sensor Count Reduced from Six--Eight to Four (Approved 2026-02-16).** The original design specified six to eight pressure sensors requiring an analog multiplexer (CD74HC4067). During prototyping, it was determined that four sensors cover the four critical finger contact points (index finger, middle finger, thumb, and ring finger) while eliminating multiplexer complexity and reducing component count. The nRF52840 provides six analog input pins, of which four are used for pressure sensors with two reserved for future expansion.

**CP-2: Phase 1 Budget Variance (Documented 2026-02-16).** The original Phase 1 budget estimate was \$64. Actual Phase 1 spending was \$104, driven by the addition of a soldering iron kit (\$20) and a resistor assortment (\$9) not included in the original estimate, plus higher-than-estimated sensor costs.

**CP-3: Microcontroller Changed from ESP32 to nRF52840 (Approved 2026-03-04).** Research into prior art identified the nRF52840 as the platform used by the closest commercial comparators: PitchLogic reports using it in its smart baseball, and the Kookaburra SmartBall uses it in its cricket ball. The nRF52840 offers significantly lower power consumption (approximately 8 mA during BLE transmission [@nordic_nrf52840] versus roughly 130 mA for ESP32 Wi-Fi [@espressif_esp32]), integrated BLE 5 with 2 Mbps throughput, a hardware floating-point unit for on-board DFT computation, and ultra-low-power sleep modes drawing less than 1 µA. The Seeed XIAO nRF52840 (21 x 17 mm, \$10) serves as the development board, with the bare QFN-48 package (7 x 7 mm) on the final custom PCB. Implementation note: the Seeed nRF52 mbed-enabled Boards package is required in the Arduino IDE; the non-mbed package produces compilation errors related to the Adafruit USB CDC driver.

**CP-4: Wireless Protocol Changed from Wi-Fi to BLE 5 Only (Approved 2026-03-04).** The original design included Wi-Fi capability via the ESP32. Analysis of PitchLogic's architecture showed that BLE 5 provides sufficient bandwidth for pitch data transmission while reducing active power draw from approximately 130 mA (Wi-Fi) [@espressif_esp32] to approximately 8 mA (BLE) [@nordic_nrf52840], extending estimated battery life from less than one hour to eight to ten hours on a 100 mAh cell. Wi-Fi capability is no longer included.

**CP-13: Harness Rebuilt on a Solderless Ferrule Interconnect (Adopted 2026-08).** Analysis of the July data collection identified progressive inter-channel electrical bridging in the first instrument's wiring, which invalidated its per-finger results (see the milestones for the diagnosis). The harness was rebuilt with a solderless interconnect: crimped ferrules and factory-terminated housed contacts replace soldered joints at the microcontroller pin row, every conductor is individually insulated, and channel independence is verified by an instrumented crosstalk test at each assembly stage rather than assumed. This change affects fabrication method only; the measurement principle, sensor selection, and analysis pipeline are unchanged.

**CP-14: Sampling Rate Raised to 480 Hz by Decoupling Acquisition from Transmission (Adopted 2026-08).** The original firmware transmitted one sample per Bluetooth notification, which capped the sampling rate near the measured link ceiling of approximately 151 Hz and left the release transient spanned by only three to four samples. Because the constraint was the notification rate rather than the sensor or converter, the firmware was changed to sample at 480 Hz into a buffer and transmit four samples per notification. The notification rate is unchanged at 120 s⁻¹, so the link operates within its measured capability. This change makes rate of force development and per-finger release ordering computable, both of which had been excluded from the earlier analysis plan as unresolvable. The packet timestamp was simultaneously changed from millisecond to microsecond resolution to remove a reconstruction artifact described in the design specification.

**CP-12: Ball-Flight Metrics Sourced from TrackMan; On-Board Inertial Sensing Removed (Approved 2026-07).** Following fabrication of the custom PCB (see milestones), ball-flight metrics were sourced from the Oral Roberts University TrackMan Doppler radar rather than from on-board inertial sensors. This refinement removes the H3LIS331DL accelerometer, the LIS3MDL magnetometer, and the DFT spin-rate and integration-based velocity methods from the deployed instrument, which is built on the Seeed XIAO nRF52840. TrackMan provides release velocity for pitches it successfully tracks, letting the project concentrate on the grip-pressure measurement it uniquely provides while pairing it with an established external reference. Velocity is the only ball-flight quantity the analysis uses. The deployed instrument streams raw ADC over BLE 5; force calibration and pitch segmentation are performed in post-processing. Per-pitch grip records are joined to their TrackMan records by a shared identifier assigned during capture.

# MILESTONES AND/OR DOCUMENTATION OF IMPLEMENTATION, OBSERVATIONS, AND EXPERIENCES

This section documents implementation chronologically, including the two findings that most shaped the final instrument: the discovery that the first build's channels were not electrically independent, and the consequent redesign of the interconnect and verification procedure.

Phase 1 (Proof of Concept) completed February 16, 2026, and Phase 2 (nRF52840 Migration and Sensor Integration) on March 23, 2026. The custom printed circuit board was fabricated but non-functional, and the instrument was rebuilt on the Seeed XIAO nRF52840 with ball-flight metrics sourced externally (CP-12). A first instrument was completed and used for data collection in July 2026. Analysis of that data identified inter-channel bridging, which invalidated its per-finger results; a second instrument was built in August 2026 with a solderless interconnect and a verified channel-isolation procedure (CP-13), and the sampling rate was raised to 480 Hz (CP-14).

## Phase 1: Proof of Concept (2026-02-16)

**Objective.** Validate the core data pipeline by building a breadboard prototype with pressure sensing, inertial measurement, and wireless data transmission.

**Implementation Summary.** The DFRobot Beetle ESP32 microcontroller was configured with the Arduino IDE and ESP32 board support package. The Adafruit MPU-6050 IMU was soldered and connected via I2C (SDA/SCL pins), and three-axis accelerometer and gyroscope readings were verified. One FlexiForce A301 pressure sensor was wired to analog pin A0 (GPIO 36) through a 10 k$\Omega$ voltage divider circuit, producing a 12-bit ADC reading proportional to applied force. Firmware was developed to read the pressure sensor and IMU concurrently at 20 Hz and transmit the combined data string via BLE. The device advertises as "SmartBaseball" and was successfully connected and read using the nRF Connect mobile application. A real-time 3D baseball visualization was built in Processing to display IMU orientation and pressure data over a serial connection.

**Key Technical Findings.**

1. *Pin mapping.* The Beetle ESP32 analog pins do not respond to the standard Arduino A0--A3 macros. GPIO numbers must be used directly in firmware: A0 = GPIO 36, A1 = GPIO 39, A2 = GPIO 34, A3 = GPIO 35.
2. *FlexiForce wiring.* The A301 sensor has three pins, but the center pin (Pin 2) is electrically inactive. Only the two outer pins are used, one connected to 3.3 V and the other to the ADC input through a 10 k$\Omega$ pull-down resistor.
3. *Resistor requirement.* Each FlexiForce sensor requires its own voltage divider resistor. Without the resistor, the ADC input floats above 2,000 counts (of 4,095), producing unusable readings.
4. *BLE compilation time.* The first build incorporating the ESP32 BLE library requires three to five minutes due to library compilation. Subsequent incremental builds are significantly faster.
5. *Sensor direct-wiring feasibility.* With four analog pins available, four sensors can be read directly without a multiplexer, simplifying the Phase 2 circuit (see CP-1 above).

**Phase 1 Actual Budget.** Table 5 itemizes Phase 1 spending. The variance against the \$64 estimate is documented in CP-2 and is attributable chiefly to tooling that the original estimate omitted.

::: {custom-style="Table Caption"}
Table 5. *Phase 1 actual budget.* Amounts are actual expenditure in U.S. dollars.
:::

| Component | Cost |
|:---|:-----|
| DFRobot Beetle ESP32 | \$12 |
| FlexiForce A301 (x2) | \$50 |
| Adafruit MPU-6050 | \$7 |
| Breadboard and wire bundle | \$6 |
| Soldering iron kit | \$20 |
| Resistor kit (assorted) | \$9 |
| **Phase 1 Total** | **\$104** |

**Deliverable.** A working breadboard prototype that reads one pressure sensor and a six-axis IMU, transmits the combined data wirelessly via BLE, and drives a real-time 3D baseball visualization. Phase 1 confirms the viability of the core sensor-to-display data pipeline and establishes the hardware and firmware foundation for Phase 2 expansion to a four-sensor array.

## Phase 2: nRF52840 Migration + Sensor Integration (2026-03-23)

**Objective.** Migrate from the Phase 1 ESP32 platform to the nRF52840, integrate the four FlexiForce A301 pressure sensors, and implement BLE 5 data streaming to a companion logger.

**Hardware Setup.** The Seeed XIAO nRF52840 development board was configured with the Arduino IDE using the Seeed nRF52 mbed-enabled Boards package (the non-mbed package produced undefined reference errors related to the Adafruit USB CDC driver). The board was selected as "Seeed XIAO BLE - nRF52840" under the mbed-enabled boards menu. The XIAO's pin labeling was confirmed: silk screen labels 0 through 5 correspond to A0 through A5 in Arduino code.

Four FlexiForce A301 pressure sensors (25 lb / 111 N range) were wired to analog pins A0 through A3 using 10 k$\Omega$ voltage divider circuits. Two breadboards were snapped together to provide adequate space: the first breadboard holds the XIAO and I2C sensor breakouts, while the second holds the four voltage divider circuits for the FlexiForce sensors. Power rails were bridged between breadboards with jumper wires from the XIAO's 3V3 and GND pins.

Inertial breakouts were evaluated on the bench during this phase but were excluded from the deployed instrument, which sources ball-flight metrics from the ORU TrackMan system rather than on-board inertial sensing (see CP-12).

**Firmware Development.** A BLE streaming firmware was developed using the ArduinoBLE library, advertising as "SmartBall" and exposing a pressure notify characteristic that carries a millisecond timestamp and the four raw pressure ADC values. The device was successfully discovered and connected using the nRF Connect application. Raw ADC is streamed rather than converted force, so that per-sensor calibration is applied in post-processing (see the calibration milestone) and can be refined without re-collecting data. A separate sketch captured single-sensor readings against known loads for calibration. Release is identified in analysis from the drop-out of grip force rather than by an on-board state machine, and the sampling rate was subsequently fixed at 120 Hz based on the measured Bluetooth notification throughput.

**Grip Mapping.** Finger contact points were mapped for four pitch grips (four-seam fastball, two-seam fastball, changeup, and curveball) to determine optimal sensor placement for the index finger, middle finger, thumb, and ring finger positions.

**Key Technical Findings.**

1. *FlexiForce sensitivity.* The A301-25 sensor (111 N full range) produces low ADC readings for casual finger pressure (approximately 20 to 120 out of 4,095), which is expected given that a two-finger squeeze applies only 1 to 2 N of the sensor's 111 N range. Pitching forces of 40 to 100 N per finger will produce readings of approximately 1,000 to 2,500, utilizing a substantial portion of the measurement range.
2. *Board package selection.* The Seeed nRF52 mbed-enabled Boards package is required for the XIAO BLE. Installing the non-mbed "Seeed nRF52 Boards" package produces linker errors referencing undefined Adafruit\_USBD\_CDC symbols.
3. *USB reconnection.* After disconnecting and reconnecting the XIAO via USB-C, the device occasionally requires a double-tap of the reset button to re-enter bootloader mode and appear as a COM port.

**Phase 2 Budget.** Table 6 itemizes Phase 2 spending, which was limited to the replacement microcontroller because the sensors and passives had been purchased in Phase 1.

::: {custom-style="Table Caption"}
Table 6. *Phase 2 budget.* Amounts are actual expenditure in U.S. dollars.
:::

| Component | Cost |
|:---|:-----|
| Seeed XIAO nRF52840 | \$10 |
| **Phase 2 Total** | **\$10** |

**Status.** Phase 2 hardware integration and BLE streaming were completed on March 23, 2026. The four pressure channels streamed over BLE 5 to a host running the nRF Connect application, with each sample carrying the ball's own timestamp. Per-sensor calibration and pitch segmentation are performed in post-processing.

**Observation carried forward.** Bench validation at this stage confirmed that each channel *responded* to pressure on its own sensor. It did not test whether a channel responded *only* to its own sensor. That distinction proved consequential and is the subject of the July findings below.

## Instrument Fabrication --- (2026-07)

A custom rigid PCB was designed and fabricated during this phase, but both assembled boards were non-functional---a hard 3.3 V-to-ground short that systematic isolation traced to an assembly defect rather than a design error, with the vendor's engineering review confirming that the submitted design files were correct. With the fabrication timeline exhausted, the deployed instrument was built on the Seeed XIAO nRF52840. Ball-flight metrics were sourced from the Oral Roberts University TrackMan system rather than on-board inertial sensors (see CP-12).

## Grip-Pressure Instrument: Firmware, Calibration, and Build --- (2026-07)

The firmware samples the four FlexiForce channels and streams raw ADC over BLE 5; a companion Python logger records the stream to timestamped CSV with per-pitch tagging. The first instrument sampled at 120 Hz, selected after a bench measurement showed a notification ceiling near 151 Hz when 200 Hz was requested. All four sensors were calibrated against a scale-referenced force standard using the conductance model of Equation (3). Measured battery runtime is approximately eight hours on a full charge, sufficient for a full data-collection session. The instrument was assembled into a regulation baseball with the electronics potted in epoxy and the charge lead exposed through a leather window.

## First Data Collection --- (2026-07-15 and 2026-07-21)

Two paired collection sessions were conducted at the ORU TrackMan facility across two pitchers, capturing fastballs and curveballs at graded effort. The instrument survived live pitching in both sessions at velocities above 80 mph, streamed continuously, and reported battery state through the sealed cover. Two results from these sessions are reported in this document; a third was subsequently withdrawn.

**Flight validation (retained).** An A/B comparison threw the instrumented ball and a regulation ball in alternating blocks, with ball flight measured externally. This comparison uses no grip channels and is therefore unaffected by the wiring finding below. Velocity was substantially preserved (approximately 1.7 mph lower for the instrumented ball) and spin rate was consistently lower by approximately 168 rpm, negative in all four effort-by-pitcher cells and replicated across both pitchers. This establishes that the instrumented ball flies closely enough to a regulation ball for its grip measurements to be interpreted in a normal pitching context, while quantifying the spin penalty the added mass and altered interior impose.

**Per-finger grip results (withdrawn).** Quality-control analysis of the raw channels identified that the sensor channels were not electrically independent, as described next. All per-finger results from these sessions---grip signatures, inter-finger correlations, and grip-to-outcome relationships---are therefore withdrawn and are not reported.

## Channel-Independence Failure: Diagnosis and Method --- (2026-07-29)

**Finding.** Cross-channel analysis of the raw ADC streams showed that channels 1 and 4 were correlated at $r = 0.999$ in every session, including the first, and that channel 3's coupling to them grew across sessions from $r = 0.49$ to $0.91$ to $0.99$. Three of four nominally independent channels were carrying substantially the same signal.

**Cause.** The affected channels were wired to physically adjacent pads on the microcontroller header using bare conductors terminated by hand-soldered joints. Flux residue and unsleeved conductor at the pad row provided a progressive conduction path between adjacent channels, which explains both the immediate coupling of the closest pair and the growth of coupling over successive sessions.

**Why bench testing did not catch it.** The pre-deployment check confirmed that each channel responded when its own sensor was pressed. Every channel passed that test, and continued to pass it, because a bridged channel still responds to its own sensor---it merely responds to others as well. A test of *responsiveness* cannot detect a loss of *independence*.

**Diagnostic method.** Three checks were adopted, and together they constitute a transferable quality-control procedure for multi-channel embedded sensor arrays:

1. *Cross-channel correlation of raw signals.* Independent channels driven by independent physical inputs should not correlate strongly. Correlation approaching unity is presumptive evidence of a shared path.
2. *Fixed-ratio testing across force.* A resistive bridge produces a coupled response that is a fixed *fraction* of the driving channel, so the ratio holds constant as the driving force changes. Mechanical coupling transmitted through the ball produces a ratio that varies with force. The distinction separates an electrical fault from a physical one.
3. *Single-channel isolation testing.* One sensor is loaded at a time and every other channel is observed. All non-driven channels must remain below 5 percent of the driven channel.

The third check is the operational gate, and it is the check the first instrument never had. It is now performed after wiring, after coating, after potting, after stitching, and before every data session.

## Second Instrument: Rebuild and Verification --- (2026-08)

The instrument was rebuilt with the solderless ferrule interconnect described in the design specification (CP-13) and the 480 Hz firmware (CP-14). Figure 5 contrasts the two interconnect designs.

Two photographs comparing interconnect designs: the first instrument with hand-soldered joints and exposed conductor on adjacent pads, and the second with each lead in an insulated housed contact and the junction moved away from the board.

::: {custom-style="Figure Caption"}
Figure 5. *Interconnect design, first and second instruments.* Panel (a): sensor leads terminated by hand-soldered joints directly on the microcontroller's analog pad row, leaving bare conductor and flux residue spanning physically adjacent pads. Panel (b): each lead terminated in an insulated housed contact that seats on the pin, with the multi-conductor junction formed in a crimped ferrule positioned away from the board. The reader should observe that the failure mechanism is not the choice of adjacent pins but the presence of exposed conductor at the pad row: the second instrument uses the same four adjacent pins and achieves cross-channel response at the converter noise floor. Relocating the junction away from the board and insulating every conductor, rather than spacing the channels apart, is what eliminated the coupling.
:::

**Verification.** With the harness complete, the isolation test was run under controlled single-pad loading. Across all four channels, driving one channel to a peak of 596 to 691 ADC counts above baseline produced responses of 2 to 4 counts on every non-driven channel---**0.3 to 0.7 percent**, against the 5 percent requirement. Coupling was additionally shown to be independent of drive level: raising the driving channel from approximately 480 to 680 counts left the coupled response unchanged at under one count, which is the signature of converter noise rather than a shared electrical path. A bridge would have scaled proportionally.

**Verification under load.** The isolation result was confirmed in live throwing rather than only on the bench. During a fastball, the three contacted channels rose to 373, 191, and 381 counts while the uncontacted fourth channel remained between 21 and 26 counts and did not follow. This is the condition the first instrument failed, tested in the configuration where it matters.

**Instrument state.** The rebuilt instrument samples at 478 Hz measured, streams continuously on battery power, reports battery state through the sealed cover, and holds channel isolation at the noise floor. Table 3 gives the sensor-to-finger mapping; Table 1 gives the calibration.

## Second Data Collection --- (2026-08)

Paired grip-pressure and ball-flight data were collected using the rebuilt instrument across multiple pitchers for two pitch types. Participants, protocol, and analyzable sample size are reported in the Data Analysis and Results section, together with the fitted results.

# DATA ANALYSIS AND RESULTS

This section reports the empirical work in five parts: the participants and protocol, the instrument-validation results that do not depend on any grip--outcome relationship, the analysis plan specified before the outcome data were inspected, the grip-force results, and the interpretive limits within which all of it must be read.

## Participants and Protocol

**Participants.** Three pitchers were recruited from the Oral Roberts University baseball program and are identified in all data and reporting by anonymous codes (P1, P2, P3). Each was informed of what the instrument measures and how the data would be recorded and used, and each confirmed that they understood the data collection and agreed to their data being used in this study; participation was voluntary. Table 7 summarizes their characteristics and the pitches contributed.

::: {custom-style="Table Caption"}
Table 7. *Participant characteristics and pitch counts, by pitcher.* Anthropometrics are self-reported. Warm-up throws carry a velocity but were thrown outside the effort protocol and are excluded from every model; unpaired pitches are those for which the Doppler reference returned no reading. "Analyzable" is the count entering the grip--outcome analyses. The reader should observe that the three pitchers are closely matched in age and stature, that P2 contributes the largest raw count but the smallest analyzable count, and that the analyzable total of 63 is what every inferential $n$ in this section is drawn from.
:::

| Pitcher | Age (y) | Height (cm) | Mass (kg) | Fastballs | Curveballs | Warm-ups | Paired | Unpaired | Analyzable |
|:--|--:|--:|--:|--:|--:|--:|--:|--:|--:|
| P1 | 23 | 190.5 | 83.9 | 16 | 8 | 0 | 23 | 1 | 23 |
| P2 | 20 | 182.9 | 77.1 | 20 | 14 | 7 | 24 | 10 | 17 |
| P3 | 21 | 188.0 | 93.0 | 17 | 8 | 0 | 23 | 2 | 23 |
| **All / mean** | **21.3** | **187.1** | **84.7** | **53** | **30** | **7** | **70** | **13** | **63** |

Anthropometrics are reported to describe the sample and are used for nothing else. With three participants, any between-pitcher covariate is perfectly confounded with pitcher identity, so height, mass, and age cannot enter a model without the model simply relabeling the pitcher.

Sessions ran 16 to 30 minutes each at a measured 475 to 477 Hz with zero non-monotonic samples. Eighty-three pitch events were segmented from the pressure records; 70 carried a tagged outcome, of which 7 were warm-up throws, leaving 63 analyzable pitches (41 fastballs, 22 curveballs).

**Protocol.** Each pitcher threw from a mound at regulation distance after a self-directed warm-up, using the facility's normal throwing protocol. Fastballs were thrown across a graded effort ladder at approximately 60, 80, and 100 percent of maximum effort, and **all three pitchers completed the full ladder**. Curveballs were thrown at competitive effort. The ladder follows the submaximal design used by Kinoshita et al. [@kinoshita2017]: it induces the velocity range required to estimate a within-pitcher force--velocity relationship, and, as this section will show, it is also the only reason that relationship can be interrogated at all.

Grip contact points were marked on the ball's cover, and each pitcher placed their fingers on those marks before each pitch. Pitches were tagged individually during capture.

**Effort labeling.** Commanded effort was recorded in the marker typed at capture, by one of two conventions: an explicit percentage prefix on the pitch's own tag, or a state marker declaring the effort for the block that followed. Where a pitch carries neither, it was thrown at maximum effort and is labeled 100 percent. Of the 63 analyzable pitches, 19 carry an explicit prefix, 8 inherit an active state marker, and 36 take the maximum-effort default. **Effort was never inferred from velocity.** Doing so would be circular: it would guarantee that commanded effort predicted velocity and would manufacture the very confound this section exists to measure.

**Inclusion and exclusion.** A pitch is analyzable if (a) the pressure record contains a complete pitch event with at least two fingers loaded above 2 N, (b) the record contains no data gap within the release window, (c) an outcome measurement was captured and tagged to that pitch, and (d) the throw was part of the effort protocol rather than a warm-up. Pitches failing (c) or (d) are retained for grip-only description and reported in Table 7, but are excluded from every grip--outcome analysis rather than shifted in sequence.

**Data integrity checks applied before analysis.** Each session file was checked for monotonic sample timing, effective sampling rate within tolerance of 480 Hz, estimated packet loss, and channel isolation re-verified against the 0.3 to 0.7 percent baseline established at build. All three sessions passed. Separately, the marker parser was validated against every tag format present in the captures; two defects were found and corrected before analysis, described in the reproducibility appendix, one of which had been silently discarding the velocity of any pitch whose tag also carried movement data.

## Instrument Validation

**Channel independence.** The isolation results reported in the milestones---0.3 to 0.7 percent cross-channel response on the bench, and non-following of the uncontacted channel under live throwing---establish that the four channels measure independent physical inputs. This is a precondition for every per-finger result that follows, and it is stated as a result rather than assumed because the first instrument failed it.

**Flight fidelity.** The A/B comparison reported in the milestones establishes that the instrumented ball's velocity is substantially preserved relative to a regulation ball and that its spin rate is consistently lower by approximately 168 rpm. Grip measurements are therefore obtained from a ball that flies close to, but not identically to, a regulation ball, and the spin offset is quantified rather than assumed negligible.

**Temporal fidelity.** Figure 6 shows a representative pitch with its release window expanded.

Two-panel grip-force trace for one fastball. The left panel shows index, middle, and thumb force in newtons over the full pitch with each digit's peak marked; the right panel expands the final milliseconds, showing the thumb unloading before the end of ball contact.

::: {custom-style="Figure Caption"}
Figure 6. *Representative grip-pressure trace for a single fastball (P1).* Panel (a): the full pitch, all three instrumented digits, force in newtons against time, sampled at 480 Hz. Filled markers indicate each digit's peak. Panel (b): the final 60 ms expanded, with hollow markers at each digit's release point---the last sample above 10 percent of that digit's peak---and a dashed rule at each. The reader should observe three things: the three digits load together over roughly 200 ms and peak within a few milliseconds of one another; the middle finger carries far less force than the index and thumb on this grip; and the thumb unloads first, clearing its threshold 16 ms before the finger channels reach the end of the pitch window on this pitch---an interval that should be read as the thumb's lead on the end of ball contact rather than as an ordering of two independently resolved release events, for the reason given in the limitations. It is the second panel that the 480 Hz sampling rate exists to produce; at 120 Hz the entire expanded window spans about seven samples.
:::

**Grip configuration is recoverable from force alone.** The four-position array was justified on the grounds that it would capture information a two-sensor instrument could not. Figure 7 shows the distribution of peak force between digits for each pitcher and pitch type.

Horizontal stacked bars of the share of total peak grip force carried by index, middle, and thumb, for each pitcher on fastballs and curveballs. Thumb share falls from about forty percent on fastballs to under ten percent on curveballs while middle share rises correspondingly.

::: {custom-style="Figure Caption"}
Figure 7. *Share of total peak grip force carried by each digit, by pitcher and pitch type.* Each bar is the mean across that pitcher's pitches of the given type; segments sum to 100 percent. FA denotes fastball, CU curveball. The reader should observe that the pattern is nearly identical across the three pitchers, that the thumb's share collapses from roughly 40 percent on the fastball to between 6 and 9 percent on the curveball, and that the middle finger absorbs almost exactly what the thumb gives up while the index share barely moves. The curveball does not grip harder; it redistributes the same grip.
:::

That redistribution is large enough to be recovered by a classifier. A logistic regression on five grip features---the three digit force shares, inter-finger discrepancy, and thumb release lead---was evaluated by cross-validation over all 63 analyzable pitches, with no ball-flight measurement entering the model. All three pitchers threw curveballs, so leave-one-pitcher-out is a genuine three-fold test in which each fold is trained without the tested pitcher entirely.

::: {custom-style="Table Caption"}
Table 8. *Pitch-type classification from grip force alone.* Accuracies are means over cross-validation folds. The permutation test shuffled pitch-type labels within pitcher and re-ran the entire leave-one-pitcher-out procedure 5,000 times. The reader should observe that accuracy is essentially unchanged between the two validation schemes, which indicates the grip signature transfers to an unseen pitcher rather than encoding individual idiosyncrasy.
:::

| Validation scheme | Accuracy | What it tests |
|:--|--:|:--|
| Majority-class baseline | 0.651 | --- |
| Leave-one-pitch-out | 0.984 | generalization to an unseen pitch |
| **Leave-one-pitcher-out** | **0.986** | **generalization to an unseen pitcher** |
| Permutation null | $p = 0.0002$ | that the accuracy is not an artifact of class imbalance |

Two-way models with pitcher as a blocking factor confirm the contrast at the level of the underlying quantities: thumb share falls from 0.408 to 0.070 ($F = 242.8$, $p = 1.4 \times 10^{-22}$, partial $\eta^2 = 0.805$) and middle share rises from 0.184 to 0.515 ($F = 258.1$, $p = 3.3 \times 10^{-23}$, partial $\eta^2 = 0.814$), while index share is statistically unchanged ($p = 0.74$). Both effects replicate in all three pitchers individually.

**This is validation of the instrument, not a finding about pitching.** The grip was deliberately changed between pitch types and the sensors are fixed to the ball, so a detectable change in which channels load is the expected consequence of the protocol rather than a discovery. What it establishes is a design decision: the discriminating signal is a thumb-to-middle trade-off, and an instrument reading only the index and middle fingers---the configuration of the closest prior work [@yeh2024]---would sample the least informative channel of the three and would have no thumb channel at all.

**Release ordering.** Figure 8 reports the interval by which the thumb loses contact before the fingers. These measurements are instrument characterization rather than findings: the direction is mechanically obvious, since the ball must clear the thumb to roll off the fingertips, and the magnitude predicted nothing.

Box plots of thumb release lead in milliseconds for each pitcher on fastballs and curveballs, with individual pitches overlaid, a rule at simultaneous release and a rule at the 4.17 millisecond resolution floor. Fastball leads cluster near thirteen milliseconds; curveball leads are much shorter.

::: {custom-style="Figure Caption"}
Figure 8. *Thumb release lead, by pitcher and pitch type.* Boxes show the median and interquartile range with individual pitches overlaid. The dashed rule marks simultaneous release; the dotted rule marks the 4.17 ms resolution floor, two sample periods, below which a single pitch cannot be ordered. The reader should observe that fastball leads cluster near 13 ms and lie almost entirely above the floor in all three pitchers, and that curveball leads are markedly shorter and frequently unresolvable---so the separation is a property of the grip rather than a fixed characteristic of the hand.
:::

Across all 83 segmented pitches the thumb led by 9.8 ms (SD 6.9, median 10.5), thumb-first in 84 percent of pitches and above the resolution floor in 71 percent, differing from zero at $t = 12.95$, $p = 1.6 \times 10^{-21}$ and by Wilcoxon signed-rank $p = 3.1 \times 10^{-13}$. On fastballs alone the lead is 12.5 to 13.9 ms across the three pitchers; on curveballs it falls to between 1.8 and 6.0 ms. The index and middle fingers cannot be separated in time: their release interval is $-0.75$ ms (SD 1.28), inside the resolution floor in 98 percent of pitches. That they release as a pair while the thumb does not is what the measurement establishes.
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

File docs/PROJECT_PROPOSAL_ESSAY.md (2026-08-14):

# Project Proposal: Instrumented Baseball for Grip Pressure Analysis

## A. Project Identification

This project proposes the design and construction of an instrumented baseball that measures grip pressure distribution at finger contact points during live pitching. The system embeds six to eight thin-film force-sensitive resistors along the ball's seams, a high-range inertial measurement unit for capturing spin rate and spin axis, a Bluetooth Low Energy microcontroller for wireless data transmission, and a Qi-compatible wireless charging subsystem. The complete electronics package targets a mass below fifteen grams, preserving regulation weight and balance. By pairing grip pressure data with ball-flight dynamics in a single self-contained instrument, the project creates a measurement platform that does not currently exist
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

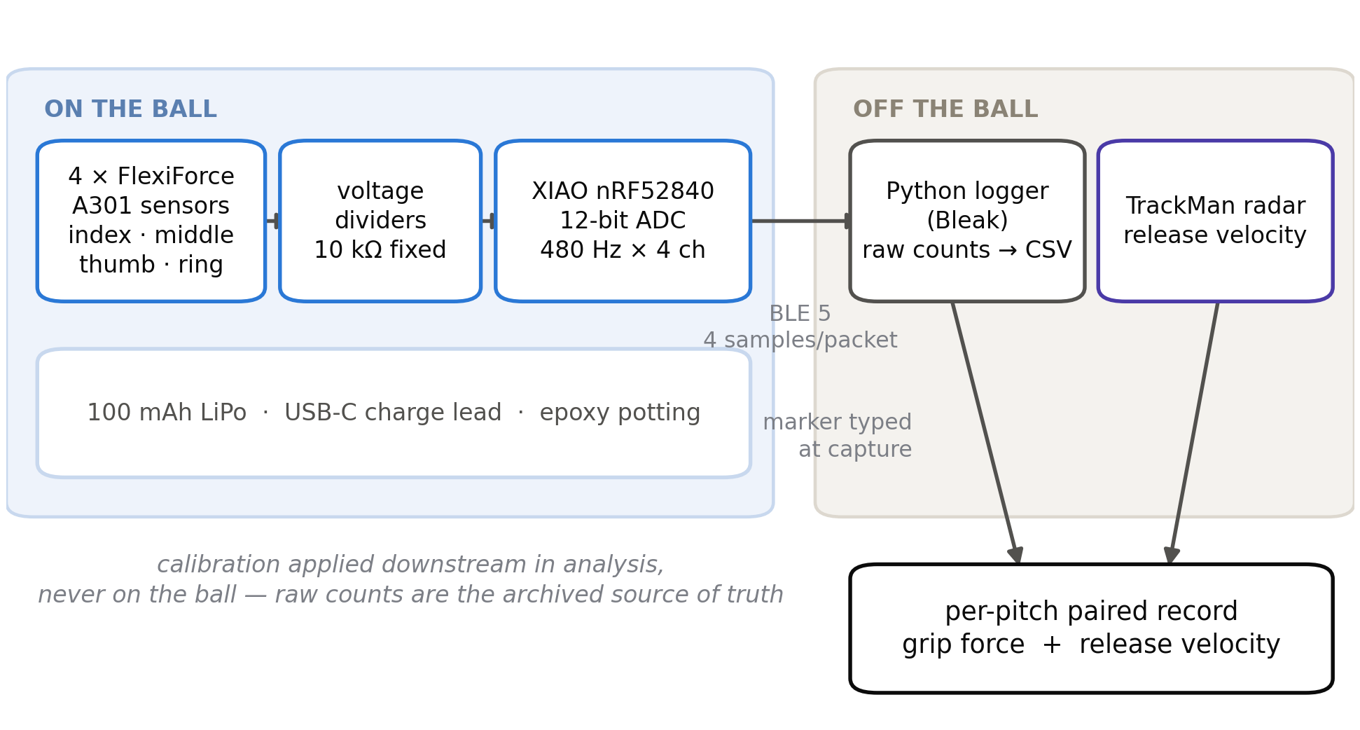
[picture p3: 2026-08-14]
figures/fig2_architecture.png

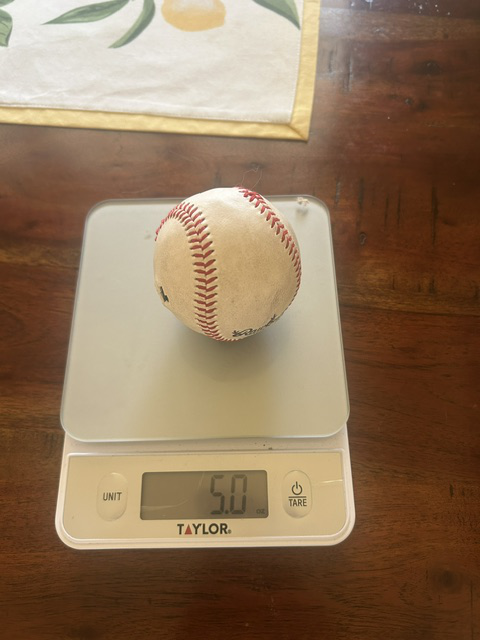
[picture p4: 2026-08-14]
figures/ball-scale-v2.jpeg

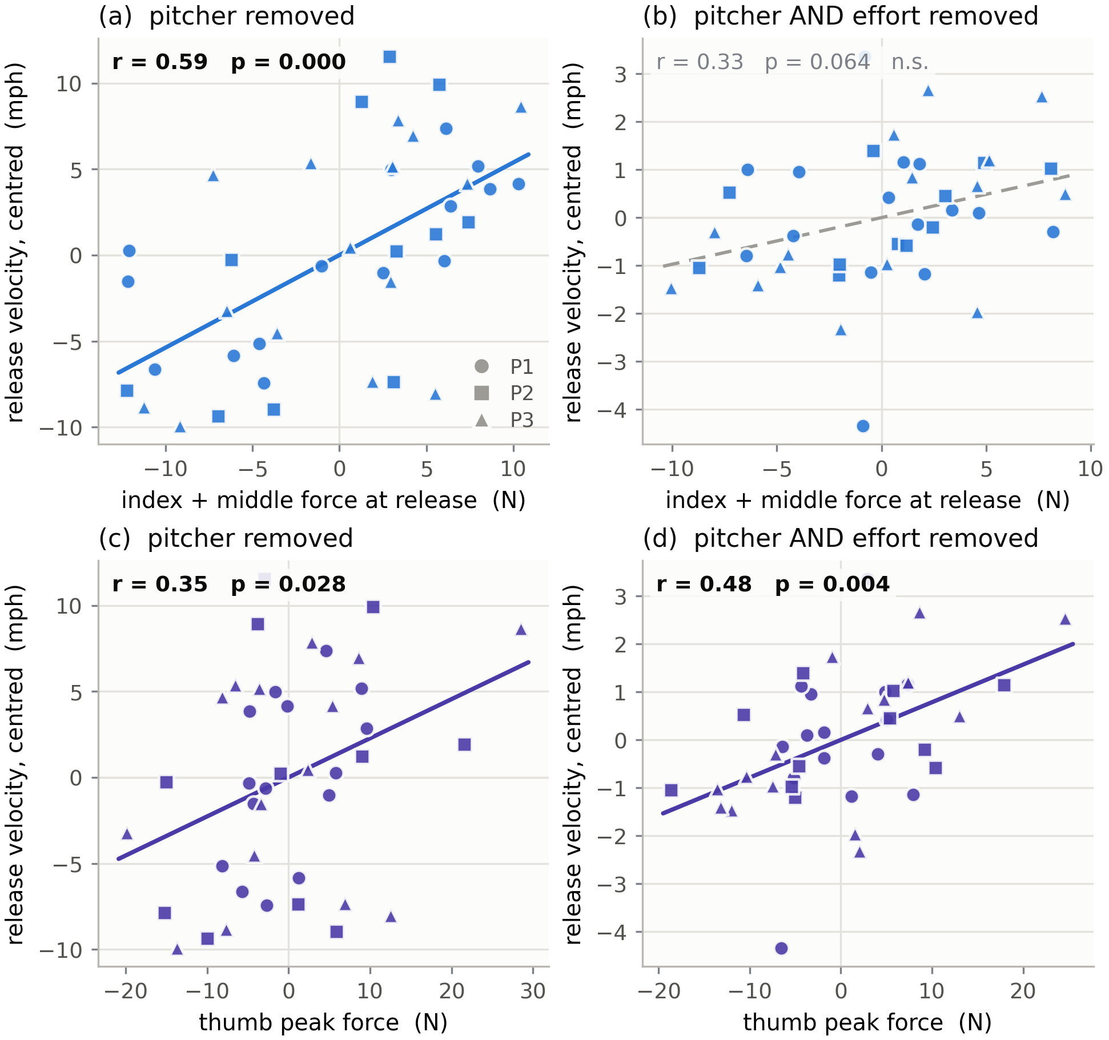
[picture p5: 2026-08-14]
figures/fig10_grip_velocity.png

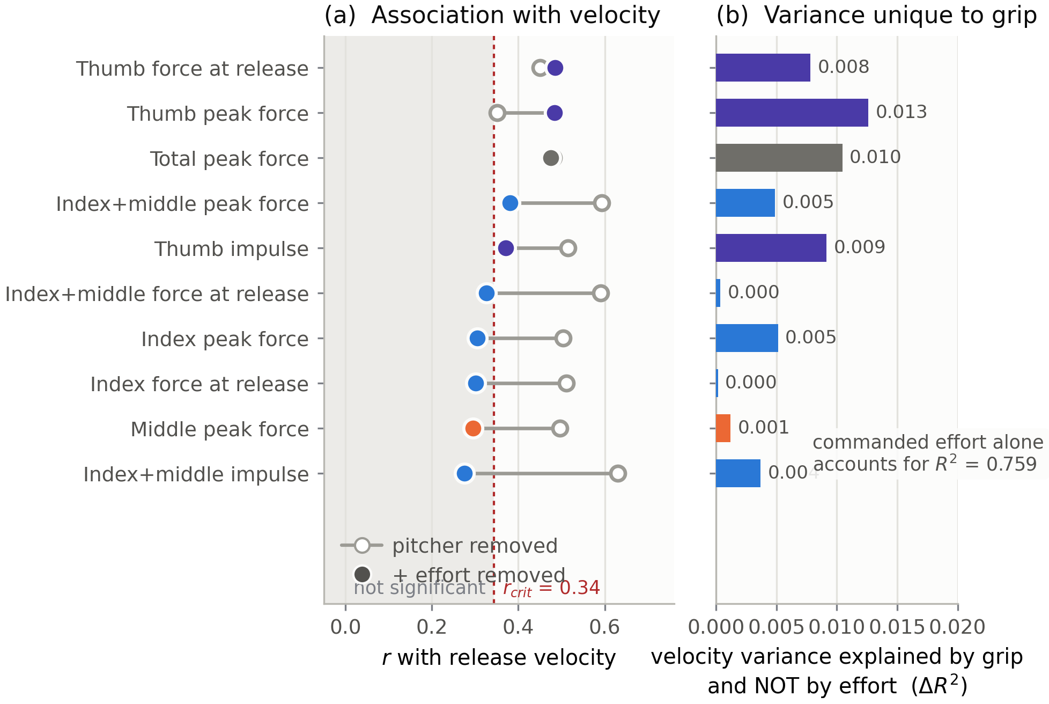
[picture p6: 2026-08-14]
figures/fig11_confound.png

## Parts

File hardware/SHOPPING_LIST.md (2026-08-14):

# Component Shopping List
## Instrumented Baseball Project

---

## Already Purchased

### Phase 1 Components (ESP32 Prototype)

| Qty | Component | Source | Cost | Status |
|-----|---|---|---|---|
| 1 | DFRobot Beetle ESP32 | DFRobot | $12 | Phase 1 only (retired) |
| 1 | MPU-6050 breakout | Adafruit | $7 | Phase 1-2 dev IMU |
| 2 | FlexiForce A201 (25 lb) | DigiKey | $50 | Purchased |
| 1 | Breadboard + Wire Bundle | Adafruit | $6 | In use |
| 1 | Soldering Iron Kit | Amazon | $20 | Purchased |
| 1 | Resistor Kit (assorted) | Amazon | $9 | Purchased |

### Phase 2 Components (Sensor Array + IMUs)

| Qty | Component | Source | Cost | Status |
|-----|---|---|---|---|
| 2 | FlexiForce A201 (25 lb) — total now 4 | DigiKey | $50 | Purchased |
| 1 | ISM330DHCX breakout | Adafruit | $12 | Purchased (Phase 2 testing; NOT on final PCB — gyro saturates) |
| 1 | H3LIS331DL breakout | Adafruit | $10 | Purchased |
| 3 | Practice baseballs | Amazon | $15 | Purchased |

### Phase 3-4 Components (Power + Integration)

| Qty | Component | Source | Cost | Status |
|-----|---|---|---|---|
| 1 | MCP73831T LiPo charger | DigiKey | $2 | Purchased |
| 1 | 100mAh LiPo battery | Adafruit | $6 | Purchased |
| 1 | Qi receiver module (20mm) | Adafruit | $10 | Purchased |
| 2 | Regulation baseballs | Amazon | $15 | Purchased |
| 1 | 30 AWG wire (50ft) | Amazon | $10 | Purchased |
| 1 | 2-part epoxy | Hardware store | $10 | Purchased |
| 1 | Conformal coating spray | Amazon | $15 | Purchased |

### nRF52840 Migration Components

| Qty | Component | Source | Cost | Status |
|-----|---|---|---|---|
| 1 | Seeed XIAO nRF52840 | Seeed Studio | $10 | Purchased |
| 1 | LIS3MDL magnetometer breakout | Adafruit | $5 | Purchased |

**Total Spent: ~$274**

---

## Order Later — When PCB Design Is Ready

| Qty | Component | Why | Source | Link | Cost |
|-----|---|-----|---|---|---|
| 5 | **Custom Rigid PCB** | ~30x25mm 2-layer rigid board (proven by McGinnis 2012) | JLCPCB | https://jlcpcb.com | $15-30 |

> **Note:** Rigid PCB, not flex. McGinnis (2012) proved a ~30x25mm rigid board fits inside a baseball. Rigid is cheaper and easier to solder.

**PCB Subtotal: $15-30**

---

## Final PCB Bill of Materials (on-board components)

| Component | Package | Qty | I2C Addr | Notes |
|---|---|-----|---|---|
| nRF52840 | QFN-48 (7x7mm) | 1 | — | Bare chip MCU, BLE 5 |
| H3LIS331DL | LGA-16 (3x3mm) | 1 | 0x18 | ±400g accel — velocity + impact |
| LIS3MDL | LGA-12 (3x3mm) | 1 | 0x1C | Magnetometer — spin rate via DFT |
| MCP73831T | SOT-23-5 | 1 | — | LiPo charge controller |
| 10kΩ Resistor | 0603 | 4 | — | Voltage dividers for FSR sensors |
| 4.7kΩ Resistor | 0603 | 2 | — | I2C pull-ups (SDA/SCL) |
| 100nF Capacitor | 0603 | 4 | — | Decoupling (near each IC) |
| 10µF Capacitor | 0603 | 1 | — | Bulk decoupling |
| 32 MHz Crystal | 3.2x2.5mm | 1 | — | nRF52840 clock |
| Chip Antenna | SMD | 1 | — | BLE 5 antenna |

> **ISM330DHCX removed from final PCB.** Its gyroscope saturates at ±4000°/s (~666 RPM per axis), which is below every real pitch. Spin rate is measured via LIS3MDL magnetometer DFT instead. Velocity is estimated by integrating H3LIS331DL acceleration data. Release detection uses FlexiForce pressure dropout.

---

## Budget Summary

| Category | Cost | Status |
|---|---|---|
| Already spent | $274 | DONE |
| Custom PCB (JLCPCB) | $15-30 | Later |
| **Grand Total** | **$289-304** | |

---

## Decision Log

| Decision | Reasoning |
|---|---|
| Switch from ESP32 to nRF52840 | 10x lower power, BLE 5, industry standard (PitchLogic, SmartBall), hardware FPU |
| Use Seeed XIAO as dev board | $10, 21x17mm, 6 analog pins, Arduino-compatible, USB-C |
| Drop ISM330DHCX from final PCB | Gyro saturates on every real pitch (±4000°/s < every pitch's spin rate). H3LIS331DL covers acceleration. LIS3MDL covers spin rate. FlexiForce covers release detection. |
| Add LIS3MDL magnetometer | DFT of mag signal measures spin rate at any RPM (Diamond Kinetics' patented approach) |
| Use H3LIS331DL for velocity | Integrate acceleration over throw duration (~0.5-1s). McGinnis showed 4-6% accuracy. |
| Rigid PCB instead of flex | McGinnis 2012 proved ~30x25mm rigid works; cheaper ($15-30 vs $50-80) |
| 4 sensors, not 6-8 | XIAO has 6 pins; 4 covers critical fingers; first study with thumb + ring data |
| FlexiForce over FSR | Calibrated, repeatable readings needed for research-grade data |
| Qi wireless charging | No exposed ports; ball can be fully sealed; charge through leather |
| Epoxy coating (not 3D frame) | Yeh et al. proved it survives 100 km/h impacts; simpler than 3D-printed frame |

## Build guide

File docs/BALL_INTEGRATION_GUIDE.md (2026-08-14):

# Ball Integration Guide — XIAO Pressure Prototype

**Goal:** embed the XIAO nRF52840 + LiPo + 4 FlexiForce sensors into a real leather
baseball so it can be gripped, thrown, and tracked by TrackMan (July 11–12).

**Design principle for this prototype: make it RE-OPENABLE, not permanently sealed.**
You will need to recharge (USB-C), reflash, and fix wiring between sessions. A ball you
epoxy shut is a ball you can't debug. Use a leather flap held by tape/lacing, not glue.

---

## Materials
- Real leather baseball (for TrackMan realism) — plus 1–2 spares to practice on
- Assembled electronics: XIAO nRF52840, LiPo, 4× FlexiForce A201, 4× 10 kΩ resistors
- Thin stranded wire (30 AWG) + solder, heat-shrink
- Seam ripper or X-acto knife, curved needle + waxed thread (or strong lacing)
- Foam / thin closed-cell padding for shock protection (NOT epoxy for this prototype)
- Small tape (electrical/gaffer), a little hot glue for tacking
- Kitchen scale (target ~5.0–5.25 oz / 142–149 g), fine-tip marker

---

## STEP 0 — Bench-test the FULL assembly first (do not skip)
Before anything goes inside the ball, confirm the complete circuit works exactly as it
will inside:
- Solder the 4 sensors + 4 resistors + XIAO + LiPo into their final wired form.
- Flash `pressure_logger.ino`, run on the LiPo (not USB), confirm BLE logs all 4 channels
  and each sensor responds to a press.
- Once it's sealed in a ball, you can't rewire — so everything must work here first.

## STEP 1 — Map the grip points
Hold a four-seam grip and mark the ball surface where each finger sits:
- **Index** and **Middle** on top (across/near the seams)
- **Thumb** underneath
- **Ring** on the side
Mark each spot with the marker and label which sensor (S1–S4) goes there.

## STEP 2 — Open the ball (re-openable flap)
- With the seam ripper, cut the stitching along **one figure-8 seam** to free a leather
  flap — enough to reach inside. Do NOT remove the whole cover; you want to close it back up.
- Peel the flap back. Under the leather is tightly wound yarn around the cork/rubber pill.

## STEP 3 — Carve the central cavity
- Dig out yarn (and shave a little of the pill if needed) to make a pocket at the ball's
  **center** sized for the XIAO + LiPo. Keep it centered — off-center mass makes it fly wrong.
- Save the removed yarn; you'll pack some back for weight.

## STEP 4 — Protect and seat the electronics
- Wrap the XIAO + LiPo in a thin layer of **closed-cell foam** (shock protection you can
  still open later). Keep the **USB-C port oriented toward the flap** so you can reach it.
- Seat the wrapped pack in the central cavity.

## STEP 5 — Route wires to the grip points
- Run each sensor's 30 AWG tail from the central electronics out through the yarn to its
  mapped grip point. Leave a little slack (strain relief) so a throw can't yank a joint.
- Tack wires down with tiny dabs of hot glue so nothing shifts.

## STEP 6 — Place sensors under the leather
- Lay each FlexiForce sensing pad **flat against the inside of the leather** at its grip
  point (index/middle/thumb/ring). The 0.2 mm sensor + leather preserves natural grip feel.
- Lightly tape or tack each in place so it can't slide.

## STEP 7 — Repack for weight & balance
- Pack yarn back around the electronics to rebuild the ball's shape and mass.
- Weigh as you go; target **~5.0–5.25 oz**. Add small packing/weight opposite any heavy
  side to keep the center of mass centered.

## STEP 8 — Close it up (re-openably)
- Fold the leather flap back down. **Re-stitch with waxed thread OR lace it snug with a
  removable stitch / strong tape** so you can reopen to charge and reflash.
- Do NOT glue it shut for this prototype.

## STEP 9 — Validate before throwing
1. Power on (battery), confirm BLE still logs (yarn/leather don't block short-range BLE).
2. Press each grip point → confirm the correct sensor channel responds.
3. Check weight and that it feels balanced in the hand.
4. Gentle **drop test** from waist height a few times → re-check it still logs.
5. A few easy test throws → confirm data survives a real throw before the pitchers arrive.

---

## Prototype tips
- **Charging/reflashing:** keep the USB-C port reachable through the flap; recharge between
  sessions and top off before each pitcher.
- **Strain relief is the #1 failure point** — the thin sensor tails tear at the solder joint.
  Slack + glue tacks + heat-shrink at joints.
- **Keep a spare ball built** if time allows — throwing tests are hard on prototypes.
- **Balance matters for TrackMan** (the ball must fly true to read), but note: grip-pressure
  data is captured *before release*, so a slightly imperfect ball still yields valid pressure
  data even if flight isn't perfect.

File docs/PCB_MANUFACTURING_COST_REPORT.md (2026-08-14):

# PCB Manufacturing Cost Analysis Report

**Project:** Instrumented Baseball for Grip Pressure Analysis (MSCS Capstone)
**Author:** Keaton Ruthardt
**Date:** April 17, 2026

---

## Executive Summary

This report analyzes PCB fabrication and assembly options for a custom 25x20mm two-layer printed circuit board required for the instrumented baseball project. The goal was to identify the lowest-cost manufacturing path that still delivers acceptable quality for a functional BLE prototype.

**Primary finding:** No United States turnkey PCB manufacturer can beat the current JLCPCB (China) quote of $445 for five fully assembled boards. Realistic paths to under $300 exist but require either reducing assembly quantity or performing assembly in-house using university facilities.

---

## Board Specifications

- Dimensions: 25 x 20 mm
- Layers: 2 (top components, bottom ground pour)
- Thickness: 0.8 mm
- Material: FR-4
- Copper weight: 1 oz
- Surface finish: ENIG
- Minimum via: 0.15 mm drill / 0.25 mm pad (required for routing under the QFN-48 microcontroller)
- Components: 29 surface-mount parts on the top side
  - 1 nRF52840 QFN-48 (7 x 7 mm, 0.4 mm pitch)
  - 1 H3LIS331DL accelerometer (LGA-16)
  - 1 LIS3MDL magnetometer (LGA-12)
  - 1 MCP73831T LiPo charger (SOT-23-5)
  - 1 AP2112K-3.3 LDO regulator (SOT-23-5)
  - 1 32 MHz passive crystal
  - 1 2.4 GHz ceramic chip antenna
  - 22 passive components (0402)

---

## Baseline: JLCPCB Quote

The current baseline quote from JLCPCB (Shenzhen, China) breaks down as follows:

| Line Item | Cost | Source |
|---|---|---|
| PCB fabrication (5 boards, 2-layer, 0.8mm, ENIG) | $85.67 | JLCPCB quote, verified |
| Small via upcharge (0.15mm/0.25mm) | $33.81 | Included in PCB line |
| ENIG surface finish upcharge | $16.90 | Included in PCB line |
| SMT assembly setup, stencil, feeders | $59.83 | JLCPCB quote |
| Components (29 parts x 5 boards) | $133.73 | JLCPCB BOM tool |
| X-ray inspection and packaging | $16.79 | JLCPCB quote |
| International shipping (DHL) | ~$40 | Estimated from quote flow |
| Customs duties and taxes | ~$100 | Current US DDP rate |
| **Total landed cost** | **~$445** | |

All component pricing was verified by cross-referencing the JLCPCB BOM matcher against LCSC part numbers.

---

## United States Manufacturer Analysis

### Eliminated by Design Constraints

**OSH Park (Portland, Oregon)** was eliminated as a fabrication option. Their published minimum via specification of 0.203 mm (8 mil) is larger than the 0.15 mm vias required for routing under the QFN-48 package. Source: OSH Park two-layer service documentation.

### Candidates Evaluated

The following United States manufacturers were evaluated against this board specification:

**Sierra Circuits (San Jose, California)** — Estimated landed cost for five boards: $600 to $900. This figure is based on their published pricing model for two-layer prototypes ($150 to $250 bare boards) combined with their Turnkey PRO assembly service, which carries a $100 minimum components charge plus setup fees of $200 to $400. No published student discount program. Note: this is an estimate based on their pricing model; an exact quote would require submitting the design.

**PCBWay (with United States partnership)** — Estimated landed cost for five boards: $450 to $550. PCBWay manufactures in China and ships through United States partner facilities for some orders, but customs treatment remains the same as JLCPCB. Their assembly pricing for QFN-48 packages typically runs 15 to 30 percent higher than JLCPCB based on published pricing. Note: these percentages come from industry comparison reports, not direct quotes.

**MacroFab (Houston, Texas)** — Estimated landed cost for five boards: $500 to $800. Their Prototype Class service pools orders to eliminate non-recurring engineering fees. Industry reports for similar boards with approximately 30 surface-mount components including one QFN suggest $80 to $150 per board for five pieces, with components charged separately via their catalog or consignment. Turnaround is a guaranteed 10 business days. No published educational discount program, though academic accommodation is sometimes available by request.

**CircuitHub (Cambridge, Massachusetts)** — Estimated landed cost for five boards: $400 to $700. Similar business model to MacroFab with online instant quoting and pooled fabrication. No published student discount.

**Screaming Circuits (Canby, Oregon)** — Estimated landed cost for five boards: $600 to $900 or more for assembly alone, plus separate PCB fabrication of approximately $150. Their pricing premium is justified by 24 to 72 hour turnaround times. Not cost-competitive for non-urgent projects.

**Worthington Assembly (South Deerfield, Massachusetts)** — Estimated assembly cost: $400 to $600. Small-batch assembly specialist oriented toward small-volume production rather than five-piece prototype runs. Would require pairing with a separate PCB fabricator.

**Tempo Automation (San Francisco, California)** — Estimated total cost: $2,000 to $4,000. Targets funded startups with three to five day turnaround times. Significantly outside budget.

**Advanced Circuits (Aurora, Colorado)** — Estimated total cost: $800 to $1,500 for PCB plus assembly. Their "BareBones" PCB service starts at approximately $33 per board but requires HASL finish; ENIG upgrade adds $50 to $100 in setup fees.

**Royal Circuit Solutions (California)** — PCB fabrication only, estimated $80 to $180 for five boards. Would require pairing with a separate assembly house.

### European Alternative

**Eurocircuits (Belgium)** — Estimated landed cost: $500 to $750 including customs, shipping, and VAT considerations. Not cost-competitive for this board quantity.

---

## Cost-Reduction Strategies

### Strategy A: Reduce Assembly Quantity at JLCPCB

JLCPCB allows ordering five bare printed circuit boards (their minimum) with only a subset of those boards receiving full surface-mount assembly. By assembling only two of the five boards, component costs drop from approximately $134 to roughly $54 while PCB fabrication costs remain unchanged.

**Estimated revised JLCPCB cost: approximately $300 to $320 total landed.**

This represents the easiest path to reduced cost with no additional work or equipment required. The remaining three bare boards can be hand-assembled later if needed, or held as spares in case of assembly defects or design revisions.

### Strategy B: Hybrid Approach Using University Facilities

This strategy separates PCB fabrication from component sourcing and assembly:

| Line Item | Estimated Cost | Notes |
|---|---|---|
| JLCPCB bare boards (5, 2-layer, 0.8mm, ENIG) | $30 to $50 | Reduced shipping without assembly weight |
| Solder paste stencil | $10 to $15 | From JLCPCB or OSH Stencils |
| DigiKey component order (5-board quantities) | $120 to $160 | See component pricing section below |
| University reflow oven access | $0 | If available in department facilities |
| **Total** | **$165 to $230** | |

This is the lowest-cost path identified. It depends on the Computing and Mathematics Department or a related engineering department having access to a reflow oven, stereo microscope, and solder paste stencil workstation. Many R1 universities maintain such facilities in shared maker spaces or research labs.

### Strategy C: Self-Assembly with Purchased Equipment

This strategy is similar to Strategy B but accounts for purchasing hot air rework equipment:

| Line Item | Estimated Cost | Notes |
|---|---|---|
| JLCPCB bare boards and stencil | $40 to $65 | |
| DigiKey components (buy 7 to 8 nRF52840 chips for margin) | $150 to $210 | Spare chips for rework learning |
| Hot air rework station | $80 to $150 | One-time equipment purchase |
| USB or stereo microscope | $30 to $200 | One-time |
| **Total for this project** | **$225 to $300** | |
| **Equipment becomes reusable for future revisions** | | |

The 0.4 mm pitch of the nRF52840 QFN-48 is at the upper difficulty range for hand soldering and requires a stencil, hot air station, and magnification. Attempting this without prior surface-mount rework experience is higher risk.

---

## Component Pricing Verification

The following component prices were verified directly from distributor product pages on April 17, 2026:

| Part | LCSC Price | DigiKey Price | Source |
|---|---|---|---|
| nRF52840-QIAA-R (1 piece) | $6.54 | $6.78 | LCSC C190794, DigiKey 1530-NRF52840-QIAA-RND |
| nRF52840-QIAA-R (10 pieces) | $6.02 | $5.87 | Same sources, quantity pricing |
| H3LIS331DLTR (1 piece) | Estimated $8 to $9 | $11.78 | DigiKey 497-15831-2-ND |
| H3LIS331DLTR (10 pieces) | Not verified | $10.25 | DigiKey, quantity pricing |

DigiKey pricing runs approximately 15 to 30 percent higher than LCSC on these parts. For a five-board run requiring ten chips each of the nRF52840 and H3LIS331DL, the DigiKey premium over LCSC is approximately $30 to $50.

The H3LIS331DL high-g accelerometer at $11.78 per unit from DigiKey represents the most expensive single component in the bill of materials, contributing approximately $59 to the five-board component total. This is consistent with JLCPCB pricing this part at approximately $13 per unit at low volumes.

---

## Tariff and Shipping Verification

According to JLCPCB's published tariff policy page, United States duties on DDP (Delivered Duty Paid) shipments were reduced by approximately 10 percent on March 17, 2026, following the expiration of fentanyl-related tariffs on February 24, 2026. The current provisional tariff is 10 percent on top of base customs duty.

The $140 combined shipping and customs line in the baseline JLCPCB quote is consistent with current DHL DDP rates and reflects the reduced post-March 2026 tariff structure. Historical reports of significantly higher tariffs refer to an earlier punitive period that is no longer in effect.

---

## Quality Assessment for 2.4 GHz BLE Application

A concern often raised about low-cost overseas PCB manufacturing is radio-frequency performance at 2.4 GHz. This concern was evaluated and found to be minimal for this specific board for the following reasons:

1. The antenna feed trace from the nRF52840 ANT pin through the matching network to the chip antenna is approximately 6 to 8 mm in length. At this short length, the difference in dielectric loss between standard FR-4 (TG-130 to TG-140) and premium low-loss substrates is below the measurement threshold.

2. The primary risks at 2.4 GHz are layout errors (antenna clearance, ground pour breaks, feedline impedance mismatches) rather than fabrication quality. These are design concerns already addressed in the PCB layout.

3. Multiple commercial products using the same nRF52840 chip, including PitchLogic (instrumented baseball) and the Kookaburra SmartBall (cricket ball), ship on Chinese-manufactured boards with no documented RF performance issues.

JLCPCB quality is therefore assessed as fully adequate for a BLE prototype at this board complexity.

---

## Recommendations

Three options are recommended in order of cost effectiveness:

**First recommendation: Strategy B (hybrid with university facilities) at an estimated $165 to $230.** The first step is to contact the Computing and Mathematics Department or the Engineering Department to inquire about access to a reflow oven and surface-mount assembly workstation. If access is available, this is the lowest-cost path by a significant margin.

**Second recommendation: Strategy A (reduced assembly quantity at JLCPCB) at an estimated $300 to $320.** If university surface-mount facilities are not available, re-quoting JLCPCB with only two boards assembled instead of five provides an approximately $125 reduction from the current $445 quote with no additional effort or equipment required.

**Third recommendation: Current JLCPCB quote at $445.** If time constraints prevent pursuing the first two options, the existing quote remains the lowest-cost option among full-service manufacturing solutions.

For comparison, the cheapest realistic United States turnkey option (MacroFab or CircuitHub) is estimated at $400 to $700 for the same board, representing a premium of approximately $100 to $300 over JLCPCB. This premium may be justifiable if the department has a preference for domestic manufacturing for supply chain or intellectual property considerations.

---

## Sources

The following sources were consulted for this analysis:

- JLCPCB quote and BOM matching tool (submitted with actual project files)
- JLCPCB United States tariff policy FAQ, effective March 17, 2026
- JLCPCB via-in-pad specifications page
- OSH Park two-layer service documentation and pricing page
- OSH Park 0.8 mm thickness service documentation
- Sierra Circuits No-Touch and Turnkey PRO service specifications
- MacroFab Prototype Class pricing documentation
- CircuitHub pricing page
- PCBWay assembly quotation system
- Eurocircuits pricing page
- DigiKey product pages for nRF52840-QIAA-R (part number 1530-NRF52840-QIAA-RND) and H3LIS331DLTR (part number 497-15831-2-ND)
- LCSC product pages for nRF52840-QIAA-R (part number C190794) and related components
- Royal Circuit Solutions service information
- Worthington Assembly company profile
- Maskset tariff analysis comparing OSH Park with imported fabrication options

---

## Notes on Figures

Figures in this report are drawn from three categories:

1. **Verified quotes:** The $445 JLCPCB baseline and specific distributor component prices were verified directly from the relevant websites or quote systems on April 17, 2026.

2. **Manufacturer pricing model estimates:** Costs for manufacturers that do not publish complete pricing (Sierra, MacroFab, CircuitHub, Screaming Circuits, Tempo) were estimated by combining their published per-service rates with industry reports from Reddit, Hackaday, and EEVblog forum discussions of similar small-board prototypes. These ranges are marked as estimates throughout.

3. **Strategy cost projections:** The totals for Strategies A, B, and C combine verified component prices, verified JLCPCB pricing for bare boards, and estimated equipment costs for the do-it-yourself option. Shipping costs within the United States are typically $10 to $20 via standard services.

All estimated ranges should be treated as planning figures rather than fixed quotes. Exact numbers for any United States manufacturer would require submitting the design for a formal quotation.

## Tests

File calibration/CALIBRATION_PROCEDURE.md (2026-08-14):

# FlexiForce A201 Calibration Procedure

## Goal
Determine a per-sensor calibration constant that converts raw ADC readings into Newtons of force, with documented accuracy.

## What You Need
- Breadboard prototype with all 4 FlexiForce sensors wired and working
- Known weights covering the expected force range:
  - Empty cup or no load (0 N baseline)
  - Light: 500 mL water bottle (~4.9 N)
  - Medium: 1 L water bottle (~9.8 N) or 1 kg dumbbell (~9.8 N)
  - Heavy: 5 lb hand weight (~22.2 N)
  - Optional: 10 lb dumbbell (~44.5 N)
- A flat hard surface
- Python 3 with numpy and matplotlib installed

## Setup
1. Place the breadboard prototype flat on a table with all 4 FlexiForce sensors face-up and free to be pressed
2. Open Arduino IDE and load `firmware/calibrate_sensors/calibrate_sensors.ino`
3. Upload to the XIAO nRF52840
4. Open Serial Monitor at 115200 baud
5. Click "Save Output to File" or be ready to copy-paste the output

## Data Collection (Repeat for Each Weight)

### Step 1: Baseline (0 N)
- With nothing touching any sensor, let the firmware stream for 10 seconds
- This captures the noise floor for each sensor

### Step 2: Apply Weight to Sensor 0 (Index Finger Sensor on A0)
- Carefully place the known weight directly on the round sensing pad of Sensor 0
- Make sure the weight is centered and not pressing on adjacent sensors
- Let it sit undisturbed for 5 seconds
- Remove the weight

### Step 3: Apply Weight to Sensor 1, 2, 3
- Repeat Step 2 for each remaining sensor

### Step 4: Repeat for Different Weights
- Repeat Steps 2-3 with each of your available weights
- More data points produce a better fit. Aim for at least 3 weights per sensor.

## Saving the Data
1. Stop the serial capture
2. Save the captured output as a CSV file (e.g., `calibration_run.csv`)
3. Open the CSV in Excel or any spreadsheet editor
4. Add two new columns at the end: `label` and `force_n`
5. For each 5-second weight-applied window, find a row near the middle of that window and fill in:
   - `label`: e.g., `S0_4.9N` or `baseline`
   - `force_n`: the applied force in Newtons (e.g., `4.9` or `0`)
6. Save the annotated CSV

Example annotated row:
```
millis,S0_avg,S0_min,S0_max,S1_avg,...,label,force_n
12500,1023,1018,1031,12,...,S0_4.9N,4.9
```

## Running the Fit
```bash
cd C:\Users\Jkeat\MastersBall\instrumented-baseball\analysis\calibration
python fit_calibration.py path\to\calibration_run.csv
```

Outputs:
- `calibration_report.png` -- A 4-panel plot showing the conductance-vs-force fit for each sensor, with R-squared value
- `calibration_constants.json` -- Machine-readable calibration constants for each sensor

## Updating the Firmware
After the fit, edit `smartball_full.ino` and update the calFactor array with the new per-sensor values from `calibration_constants.json`:

```cpp
// Before (uniform):
float calFactor[4] = {55.5, 55.5, 55.5, 55.5};

// After (from calibration):
float calFactor[4] = {52.3, 57.1, 54.8, 56.0};  // example values
```

## Acceptance Criteria
- Each sensor should have an R-squared of at least 0.95 against the linear conductance model
- Sensor-to-sensor variation in calFactor should be within plus or minus 15 percent of the average
- The calibration plot is acceptable thesis evidence for Sprint 3 deliverable

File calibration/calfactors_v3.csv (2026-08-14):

# SmartBall v2 calibration — fit_v3_calibration.py
# Model: F(N) = calFactor * ADC/(4095-ADC) | through origin.
# Weight sequence read per-file from the capture header.
sensor | calFactor_N | R2 | repeatability_cv_pct | tests | max_force_N
BK | 119 | 0.986 | 2.6 | 20 | 28.4
CD | 331 | 0.973 | 7.1 | 4 | 19.6
CG | 157 | 0.961 | 7.8 | 20 | 19.6
KA | 148 | 0.995 | 1.3 | 20 | 19.6
RM | 129 | 0.977 | 6.5 | 20 | 28.4

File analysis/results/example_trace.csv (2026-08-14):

ball_t_ms | pointer | middle | thumb | pitcher | t_rel_ms
1151998.023 | 0.9077263779527559 | 1.2403846153846154 | 2.014851485148515 | P1 | 0.0
1152000.107 | 1.1146167118560513 | 1.1120689655172413 | 2.424422933730454 | P1 | 2.084000000031665
1152002.189 | 1.1738594327990135 | 0.984005905511811 | 2.461767626613704 | P1 | 4.165999999968335
1152004.275 | 0.9372384937238494 | 1.1120689655172413 | 2.4991308666501117 | P1 | 6.251999999862164
1152006.357 | 0.8782287822878229 | 1.1441241685144123 | 2.3497891342098733 | P1 | 8.334000000031665
1152008.44 | 1.0258620689655173 | 1.3046373951652688 | 2.0891530460624073 | P1 | 10.416999999899417
1152010.52 | 0.8192771084337349 | 1.2725030826140566 | 2.163528245787909 | P1 | 12.496999999973923
1152012.608 | 0.8782287822878229 | 1.1761951700344997 | 2.014851485148515 | P1 | 14.584999999962747
1152018.71 | 0.8487456960157402 | 1.1761951700344997 | 2.200743494423792 | P1 | 20.686999999918044
1152020.796 | 1.0554323725055432 | 1.2403846153846154 | 2.1263314342333417 | P1 | 22.773000000044703
1152022.878 | 0.6427694574024061 | 1.1441241685144123 | 2.3870967741935485 | P1 | 24.854999999981374
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

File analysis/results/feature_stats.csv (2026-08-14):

feat | r_raw | p_raw | n | df | lo_raw | hi_raw | slope_raw | p_perm | holm_raw | bh_raw | r_strat | p_strat | df_strat | slope | r_add | p_add | holm_strat | bh_strat | pretty | digit | r_effort | p_effort | unique_grip | unique_effort | shared | crit_r_strat
CV_peak | -0.35649181565931154 | 0.02590621518074129 | 41 | 37 | -0.6040641827691642 | -0.04616766909258805 | -16.11519628506651 | 0.019549022548872558 | 0.12091525099316947 | 0.030477900212636813 | -0.008468057084847947 | 0.9626962567506655 | 31 | -0.09896879694392978 | 0.05532927611047459 | 0.744989811324412 | 1.0 | 0.9626962567506655 | Inter-finger discrepancy | total | -0.3944130328490624 | 0.012969114243025803 | 0.0002688618622512795 | 0.6380500016970506 | 0.10537127448807815 | 0.34395728870431536
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

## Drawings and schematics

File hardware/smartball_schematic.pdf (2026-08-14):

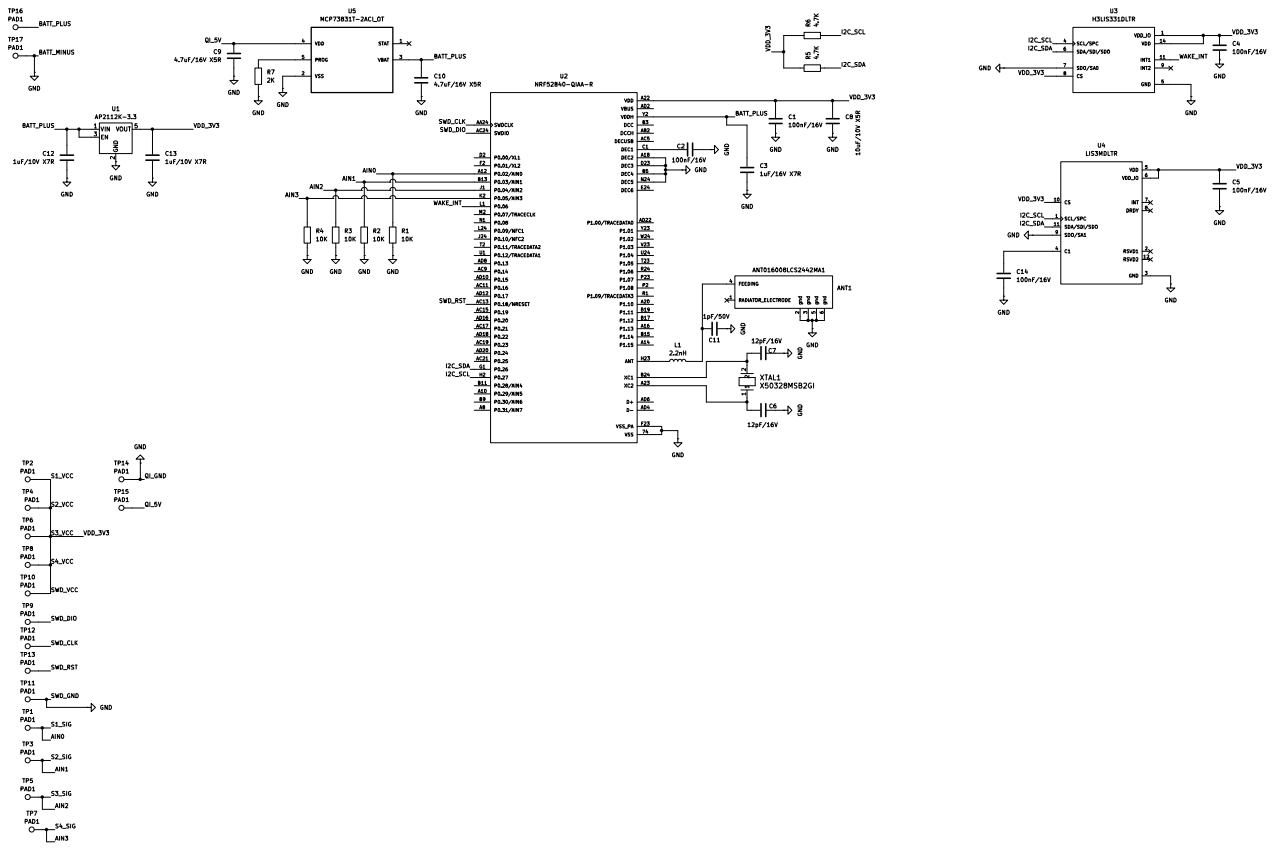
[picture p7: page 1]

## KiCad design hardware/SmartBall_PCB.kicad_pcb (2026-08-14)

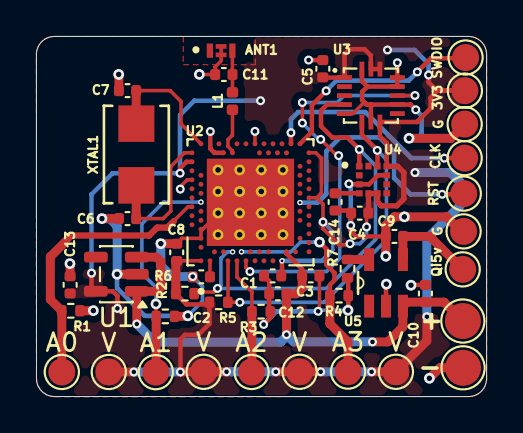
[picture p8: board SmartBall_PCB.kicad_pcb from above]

Board: 2 copper layers, 25.0 x 20.0 mm, 46 parts (0 on the bottom side), 21 nets.

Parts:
3V3: PAD1; TestPoint_Pad_D1.5mm
+: PAD1; TestPoint_Pad_D2.0mm
-: PAD1; TestPoint_Pad_D2.0mm
A0, A1, A2, A3: PAD1; TestPoint_Pad_D1.5mm
ANT1: ANT016008LCS2442MA1; ANT_ANT016008LCS2442MA1
C1, C2, C4, C5, C14: 100nF/16V; C_0402_1005Metric
C3: 1uF/16V X7R; C_0402_1005Metric
C6, C7: 12pF/16V; C_0402_1005Metric
C8: 10uF/10V X5R; C_0402_1005Metric
C9, C10: 4.7uF/16V X5R; C_0402_1005Metric
C11: 1pF/50V; C_0402_1005Metric
C12, C13: 1uF/10V X7R; C_0402_1005Metric
CLK: PAD1; TestPoint_Pad_D1.5mm
G: PAD1; TestPoint_Pad_D1.5mm
G#2: PAD1; TestPoint_Pad_D1.5mm
L1: 2.2uH; L_0402_1005Metric
Qi5v: PAD1; TestPoint_Pad_D1.5mm
R1, R2, R3, R4: 10K; R_0402_1005Metric
R5, R6: 4.7K; R_0402_1005Metric
R7: 2K; R_0402_1005Metric
RST: PAD1; TestPoint_Pad_D1.5mm
SWDIO: PAD1; TestPoint_Pad_D1.5mm
U1: AP2112K-3.3; SOT-23-5
U2: NRF52840-QIAA-R; XCVR_NRF52840-QIAA-R
U3: H3LIS331DLTR; QFN300X300X100-16N
U4: LIS3MDLTR; XDCR_LIS3MDLTR
U5: MCP73831T-2ACI_OT; SOT95P280X145-5N
V: PAD1; TestPoint_Pad_D1.5mm
V#2, V#3, V#4: PAD1; TestPoint_Pad_D1.5mm
XTAL1: X50328MSB2GI; XTAL_MSB2GI_YXC

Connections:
/AIN0: A0.1 (1_1), R1.1, U2.A12 (P0.02/AIN0)
/AIN1: A1.1 (1_1), R2.1, U2.B13 (P0.03/AIN1)
/AIN2: A2.1 (1_1), R3.1, U2.J1 (P0.04/AIN2)
/AIN3: A3.1 (1_1), R4.1, U2.K2 (P0.05/AIN3)
/BATT_PLUS: +.1 (1_1), C3.1, C10.1, C12.1, U1.1 (VIN), U1.3 (EN), U2.Y2 (VDDH), U5.3 (VBAT)
/I2C_SCL: R6.2, U2.H2 (P0.27), U3.4 (SCL/SPC), U4.1 (SCL/SPC)
/I2C_SDA: R5.2, U2.G1 (P0.26), U3.6 (SDA/SDI/SDO), U4.11 (SDA/SDI/SDO)
/QI_5V: C9.1, Qi5v.1 (1_1), U5.4 (VDD)
/SWD_CLK: CLK.1 (1_1), U2.AA24 (SWDCLK)
/SWD_DIO: SWDIO.1 (1_1), U2.AC24 (SWDIO)
/SWD_RST: RST.1 (1_1), U2.AC13 (P0.18/NRESET)
/WAKE_INT: U2.L1 (P0.06), U3.11 (INT1)
GND: -.1 (1_1), ANT1.2 (gnd), ANT1.3 (gnd), C1.2, C2.2, C3.2, C4.2, C5.2, C6.2, C7.2, C8.2, C9.2, C10.2, C11.2, C12.2, C13.2, C14.2, G.1 (1_1), G#2.1 (1_1), R1.2, R2.2, R3.2, R4.2, R7.2, U1.2 (GND), U2.74 (VSS), U2.74_1, U2.74_2, U2.74_3, U2.74_4, U2.74_5, U2.74_6, U2.74_7, U2.74_8, U2.74_9, U2.74_10, U2.74_11, U2.74_12, U2.74_13, U2.74_14, U2.74_15, U2.74_16, U2.A18 (DEC2), U2.B5 (DEC4), U2.B7 (VSS), U2.D23 (DEC3), U2.F23 (VSS_PA), U2.N24 (DEC5), U3.5 (GND), U3.7 (SDO/SA0), U3.10 (GND), U3.12 (GND), U3.13 (GND), U3.16 (GND), U4.3 (GND), U4.9 (SDO/SA1), U5.2 (VSS)
unnamed: ANT1.4 (FEEDING), C11.1, L1.2
unnamed: L1.1, U2.H23 (ANT)
unnamed: C2.1, U2.C1 (DEC1)
unnamed: C7.1, U2.B24 (XC1), XTAL1.2
unnamed: C6.1, U2.A23 (XC2), XTAL1.1
unnamed: C14.1, U4.4 (C1)
unnamed: R7.1, U5.5 (PROG)
VDD: 3V3.1 (1_1), C1.1, C4.1, C5.1, C8.1, C13.1, R5.1, R6.1, U1.5 (VOUT), U2.A22 (VDD), U2.AD14 (VDD), U2.AD23 (VDD), U2.B1 (VDD), U2.W1 (VDD), U3.1 (VDD_IO), U3.8 (CS), U3.14 (VDD), U3.15 (VDD), U4.5 (VDD), U4.6 (VDD_IO), U4.10 (CS), V.1 (1_1), V#2.1 (1_1), V#3.1 (1_1), V#4.1 (1_1)

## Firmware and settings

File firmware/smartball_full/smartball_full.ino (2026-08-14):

/*
 * SmartBall Full Firmware — Seeed XIAO nRF52840
 *
 * Features:
 *   - 4x FlexiForce pressure sensors (A0-A3) with Newton calibration
 *   - H3LIS331DL accelerometer (velocity via integration)
 *   - LIS3MDL magnetometer (spin rate via DFT)
 *   - Pitch detection (accel threshold → sample → pressure dropout = release)
 *   - On-board DFT spin rate computation
 *   - On-board velocity estimation
 *   - BLE 5 streaming of raw data + computed metrics
 *
 * State machine:
 *   IDLE     → low power, waiting for motion
 *   SAMPLING → high-rate capture during pitch event
 *   COMPUTE  → DFT + velocity after release detected
 *   TRANSMIT → send results over BLE
 */

#include <ArduinoBLE.h>
#include <Wire.h>
#include <math.h>

// ── Board Target ──
// The custom SmartBall PCB routes signals to different nRF52840 pins than the
// XIAO dev board (verified against SmartBall_PCB.kicad_pcb netlist):
//   Pressure 3/4: P0.04/P0.05 (XIAO A2/A3 are P0.28/P0.29 — unconnected here)
//   I2C bus:      P0.26/P0.27 (XIAO Wire is P0.04/P0.05 — pressure nets here)
// Set to 1 when flashing the custom PCB, 0 for the XIAO breadboard.
#define CUSTOM_BOARD 1

#if CUSTOM_BOARD
#include <mbed.h>
mbed::AnalogIn ain2Raw(P0_4);          // sensor 3 on AIN2
mbed::AnalogIn ain3Raw(P0_5);          // sensor 4 on AIN3
arduino::MbedI2C WireSB(P0_26, P0_27); // custom board I2C bus
#define I2C_BUS WireSB
#else
#define I2C_BUS Wire
#endif

// ── I2C Addresses ──
#define H3LIS_ADDR  0x18
#define LIS3MDL_ADDR 0x1C

// ── Calibration ──
// FlexiForce A201-25 (111N / 25lb range)
// Tekscan: conductance (1/R) is linear with force
// Slope from manufacturer data: ~1.8 µS/N → calFactor = 1/slope in divider units
// Circuit: 3.3V → FlexiForce → ADC → 10kΩ → GND
// ADC conductance = ADC / (4095 - ADC), so:
//   Force(N) = conductance_adc * R_FIXED / (CAL_SLOPE)
// where CAL_SLOPE = 1.8e-6 S/N and R_FIXED = 10000
// Simplifies to: Force(N) = conductance_adc * 10000 / 1.8e-6... but easier:
//   Force(N) = conductance_adc * calFactor
// calFactor = R_FIXED * CAL_SLOPE_INV = derived below
//
// From Tekscan data: at 111N, R=5kΩ → conductance_adc = 10000/5000 = 2.0
// So calFactor = 111N / 2.0 = 55.5 N per unit conductance
// Each sensor varies ±10%, recalibrate with known weight if needed.
float calFactor[4] = {55.5, 55.5, 55.5, 55.5};
const float R_FIXED = 10000.0;

// ── H3LIS331DL scale ──
// ±400g mode: 16-bit signed, full scale = 800g
// Sensitivity: 800g / 65536 = 0.01221 g/LSB
const float ACCEL_SCALE = 0.01221;  // g per LSB
const float G_TO_MS2 = 9.80665;

// ── Sampling ──
const int SAMPLE_RATE = 1000;           // Hz
const int MAX_SAMPLES = 2000;           // 2 seconds max
const float SAMPLE_PERIOD = 1.0 / SAMPLE_RATE;

// ── Pitch Detection Thresholds ──
const float ACCEL_TRIGGER_G = 10.0;     // g's to start sampling (raise if false triggers)
const int RELEASE_COUNT = 20;            // consecutive zero-pressure samples = release
const float PRESSURE_ZERO_THRESH = 10.0; // ADC below this = no contact

// ── Buffers ──
// Stored as raw int16 to save memory
int16_t pressureBuf[MAX_SAMPLES][4];
int16_t accelBuf[MAX_SAMPLES][3];
int16_t magBuf[MAX_SAMPLES][3];
int sampleCount = 0;
int releaseIndex = -1;
int zeroCount = 0;

// ── State Machine ──
enum State { IDLE, SAMPLING, COMPUTE, TRANSMIT };
State state = IDLE;

// ── Computed Metrics ──
float spinRateRPM = 0;
float velocityMPH = 0;
float peakForceN[4] = {0, 0, 0, 0};
float releaseTimeMs = 0;

// ── BLE ──
BLEService ballService("00001234-0000-1000-8000-00805f9b34fb");

// Raw streaming (same as before)
BLECharacteristic pressureChar("00001235-0000-1000-8000-00805f9b34fb",
                                BLERead | BLENotify, 8);
BLECharacteristic accelChar("00001236-0000-1000-8000-00805f9b34fb",
                             BLERead | BLENotify, 6);
BLECharacteristic magChar("00001237-0000-1000-8000-00805f9b34fb",
                           BLERead | BLENotify, 6);

// Computed pitch metrics: spinRPM(f32), velocityMPH(f32), peakForce[4](f32), releaseMs(f32) = 28 bytes
BLECharacteristic metricsChar("00001238-0000-1000-8000-00805f9b34fb",
                               BLERead | BLENotify, 28);

bool bleConnected = false;
unsigned long lastLiveUpdate = 0;

void setup() {
  Serial.begin(115200);
  delay(1000);
  Serial.println("SmartBall Full Firmware v2.0");

  analogReadResolution(12);
  I2C_BUS.begin();
  I2C_BUS.setClock(400000); // 400kHz I2C for faster reads

  initSensors();
  initBLE();

  Serial.println("Ready. Waiting for pitch...");
  Serial.println("States: IDLE → SAMPLING → COMPUTE → TRANSMIT → IDLE");
}

void loop() {
  BLE.poll();

  BLEDevice central = BLE.central();
  if (central && central.connected()) {
    bleConnected = true;
  } else {
    bleConnected = false;
  }

  switch (state) {
    case IDLE:
      doIdle();
      break;
    case SAMPLING:
      doSampling();
      break;
    case COMPUTE:
      doCompute();
      break;
    case TRANSMIT:
      doTransmit();
      break;
  }
}

// ════════════════════════════════════════
// STATE: IDLE — wait for motion
// ════════════════════════════════════════
void doIdle() {
  // Stream live data at 10Hz so the dashboard/nRF Connect can verify all channels
  if (millis() - lastLiveUpdate >= 100) {
    lastLiveUpdate = millis();
    sendLiveData();
  }

  // Check for pitch start
  int16_t ax, ay, az;
  readAccel(&ax, &ay, &az);
  float gMag = sqrt((float)ax * ax + (float)ay * ay + (float)az * az) * ACCEL_SCALE;

  if (gMag > ACCEL_TRIGGER_G) {
    Serial.println(">>> PITCH DETECTED — sampling...");
    sampleCount = 0;
    releaseIndex = -1;
    zeroCount = 0;
    state = SAMPLING;
  }
}

// ════════════════════════════════════════
// STATE: SAMPLING — capture all channels at 1kHz
// ════════════════════════════════════════
void doSampling() {
  unsigned long sampleStart = micros();

  // Read pressure
  pressureBuf[sampleCount][0] = readPressureCh(0);
  pressureBuf[sampleCount][1] = readPressureCh(1);
  pressureBuf[sampleCount][2] = readPressureCh(2);
  pressureBuf[sampleCount][3] = readPressureCh(3);

  // Read accelerometer
  readAccel(&accelBuf[sampleCount][0],
            &accelBuf[sampleCount][1],
            &accelBuf[sampleCount][2]);

  // Read magnetometer
  readMag(&magBuf[sampleCount][0],
          &magBuf[sampleCount][1],
          &magBuf[sampleCount][2]);

  // Check for release (all pressure sensors near zero)
  if (releaseIndex < 0) {
    bool allZero = true;
    for (int i = 0; i < 4; i++) {
      if (pressureBuf[sampleCount][i] > PRESSURE_ZERO_THRESH) {
        allZero = false;
        break;
      }
    }

    // Need RELEASE_COUNT consecutive zero readings to confirm release
    if (allZero) {
      zeroCount++;
      if (zeroCount >= RELEASE_COUNT) {
        releaseIndex = sampleCount - RELEASE_COUNT;
        Serial.print(">>> RELEASE at sample ");
        Serial.println(releaseIndex);
      }
    } else {
      zeroCount = 0;
    }
  }

  sampleCount++;

  // Stop conditions: buffer full or 500ms after release
  bool bufferFull = (sampleCount >= MAX_SAMPLES);
  bool postRelease = (releaseIndex > 0 &&
                      (sampleCount - releaseIndex) > 500);

  if (bufferFull || postRelease) {
    Serial.print(">>> SAMPLING DONE — ");
    Serial.print(sampleCount);
    Serial.println(" samples captured");
    state = COMPUTE;
    return;
  }

  // Wait for next sample (maintain 1kHz)
  while ((micros() - sampleStart) < 1000) {
    // spin wait
  }
}

// ════════════════════════════════════════
// STATE: COMPUTE — DFT spin rate + velocity
// ════════════════════════════════════════
void doCompute() {
  Serial.println(">>> COMPUTING metrics...");

  // ── 1. Spin Rate via DFT ──
  spinRateRPM = computeSpinRate();
  Serial.print("  Spin Rate: ");
  Serial.print(spinRateRPM, 0);
  Serial.println(" RPM");

  // ── 2. Velocity via Acceleration Integration ──
  velocityMPH = computeVelocity();
  Serial.print("  Velocity: ");
  Serial.print(velocityMPH, 1);
  Serial.println(" mph");

  // ── 3. Peak Force per Finger ──
  computePeakForces();
  Serial.print("  Peak Force (N): ");
  for (int i = 0; i < 4; i++) {
    Serial.print(peakForceN[i], 1);
    if (i < 3) Serial.print(", ");
  }
  Serial.println();

  // ── 4. Release Time ──
  if (releaseIndex > 0) {
    releaseTimeMs = (float)releaseIndex * 1000.0 / SAMPLE_RATE;
    Serial.print("  Release at: ");
    Serial.print(releaseTimeMs, 0);
    Serial.println(" ms into pitch");
  }

  state = TRANSMIT;
}

// ════════════════════════════════════════
// STATE: TRANSMIT — send over BLE
// ════════════════════════════════════════
void doTransmit() {
  Serial.println(">>> TRANSMITTING...");

  // Pack computed metrics: spin(4) + velocity(4) + peakForce[4](16) + releaseMs(4) = 28 bytes
  uint8_t metricsBuf[28];
  memcpy(&metricsBuf[0],  &spinRateRPM, 4);
  memcpy(&metricsBuf[4],  &velocityMPH, 4);
  memcpy(&metricsBuf[8],  &peakForceN[0], 4);
  memcpy(&metricsBuf[12], &peakForceN[1], 4);
  memcpy(&metricsBuf[16], &peakForceN[2], 4);
  memcpy(&metricsBuf[20], &peakForceN[3], 4);
  memcpy(&metricsBuf[24], &releaseTimeMs, 4);

  if (bleConnected) {
    metricsChar.writeValue(metricsBuf, 28);
    Serial.println("  Sent metrics over BLE.");
  }

  // Print summary
  Serial.println();
  Serial.println("════════════════════════════════");
  Serial.println("  PITCH SUMMARY");
  Serial.println("════════════════════════════════");
  Serial.print("  Spin Rate:  ");
  Serial.print(spinRateRPM, 0);
  Serial.println(" RPM");
  Serial.print("  Velocity:   ");
  Serial.print(velocityMPH, 1);
  Serial.println(" mph");
  Serial.print("  Index:      ");
  Serial.print(peakForceN[0], 1);
  Serial.println(" N");
  Serial.print("  Middle:     ");
  Serial.print(peakForceN[1], 1);
  Serial.println(" N");
  Serial.print("  Thumb:      ");
  Serial.print(peakForceN[2], 1);
  Serial.println(" N");
  Serial.print("  Ring:       ");
  Serial.print(peakForceN[3], 1);
  Serial.println(" N");
  Serial.print("  Release:    ");
  Serial.print(releaseTimeMs, 0);
  Serial.println(" ms");
  Serial.print("  Samples:    ");
  Serial.println(sampleCount);
  Serial.println("════════════════════════════════");
  Serial.println();
  Serial.println("Ready for next pitch...");

  state = IDLE;
}

// ════════════════════════════════════════
// DFT SPIN RATE
// ════════════════════════════════════════
float computeSpinRate() {
  // Use magnetometer data from free flight (after release)
  int startIdx = (releaseIndex > 0) ? releaseIndex : sampleCount / 2;
  int endIdx = sampleCount;
  int N = endIdx - startIdx;

  if (N < 50) return 0; // not enough data

  // Cap at 512 samples for speed
  if (N > 512) N = 512;

  // Frequency resolution = sampleRate / N
  float freqRes = (float)SAMPLE_RATE / N;

  // Search 5-50 Hz (300-3000 RPM)
  int binLow = max(1, (int)(5.0 / freqRes));
  int binHigh = min(N / 2, (int)(50.0 / freqRes));

  float maxMag = 0;
  int peakBin = 0;

  // DFT over magnetometer — try all 3 axes, pick strongest peak
  // First remove DC offset (mean) from each axis to prevent low-bin leakage
  for (int axis = 0; axis < 3; axis++) {
    float mean = 0;
    for (int n = 0; n < N; n++) {
      mean += (float)magBuf[startIdx + n][axis];
    }
    mean /= N;
    // Subtract mean in-place (modifies buffer but we don't need raw values after)
    for (int n = 0; n < N; n++) {
      magBuf[startIdx + n][axis] -= (int16_t)mean;
    }
  }

  for (int axis = 0; axis < 3; axis++) {
    for (int k = binLow; k <= binHigh; k++) {
      float realPart = 0;
      float imagPart = 0;

      for (int n = 0; n < N; n++) {
        float angle = 2.0 * M_PI * k * n / N;
        float sample = (float)magBuf[startIdx + n][axis];
        realPart += sample * cos(angle);
        imagPart -= sample * sin(angle);
      }

      float mag = sqrt(realPart * realPart + imagPart * imagPart);
      if (mag > maxMag) {
        maxMag = mag;
        peakBin = k;
      }
    }
  }

  // Noise floor check — if peak magnitude is too low, no real spin detected
  // Average magnitude across all bins as noise estimate
  float avgMag = 0;
  for (int k = binLow; k <= binHigh; k++) {
    float rp = 0, ip = 0;
    for (int n = 0; n < N; n++) {
      float angle = 2.0 * M_PI * k * n / N;
      rp += (float)magBuf[startIdx + n][0] * cos(angle);
      ip -= (float)magBuf[startIdx + n][0] * sin(angle);
    }
    avgMag += sqrt(rp * rp + ip * ip);
  }
  avgMag /= (binHigh - binLow + 1);

  // Peak must be at least 3x the average to be a real signal
  if (maxMag < avgMag * 3.0) return 0;

  float peakFreq = peakBin * freqRes;

  // Convert to RPM
  return peakFreq * 60.0;
}

// ════════════════════════════════════════
// VELOCITY ESTIMATION
// ════════════════════════════════════════
float computeVelocity() {
  // Integrate acceleration magnitude from start to release
  int endIdx = (releaseIndex > 0) ? releaseIndex : sampleCount;

  // Find throw start (first sustained high acceleration)
  int startIdx = 0;
  for (int i = 0; i < endIdx; i++) {
    float gMag = sqrt((float)accelBuf[i][0] * accelBuf[i][0] +
                       (float)accelBuf[i][1] * accelBuf[i][1] +
                       (float)accelBuf[i][2] * accelBuf[i][2]) * ACCEL_SCALE;
    if (gMag > ACCEL_TRIGGER_G) {
      startIdx = i;
      break;
    }
  }

  // Remove gravity bias (average of first 10 samples before trigger)
  float gravX = 0, gravY = 0, gravZ = 0;
  int biasStart = max(0, startIdx - 50);
  int biasEnd = max(0, startIdx - 5);
  int biasCount = biasEnd - biasStart;

  if (biasCount > 0) {
    for (int i = biasStart; i < biasEnd; i++) {
      gravX += (float)accelBuf[i][0];
      gravY += (float)accelBuf[i][1];
      gravZ += (float)accelBuf[i][2];
    }
    gravX /= biasCount;
    gravY /= biasCount;
    gravZ /= biasCount;
  }

  // Integrate acceleration to get velocity
  float vx = 0, vy = 0, vz = 0;

  for (int i = startIdx; i < endIdx; i++) {
    float ax = ((float)accelBuf[i][0] - gravX) * ACCEL_SCALE * G_TO_MS2;
    float ay = ((float)accelBuf[i][1] - gravY) * ACCEL_SCALE * G_TO_MS2;
    float az = ((float)accelBuf[i][2] - gravZ) * ACCEL_SCALE * G_TO_MS2;

    vx += ax * SAMPLE_PERIOD;
    vy += ay * SAMPLE_PERIOD;
    vz += az * SAMPLE_PERIOD;
  }

  // Speed magnitude in m/s
  float speedMS = sqrt(vx * vx + vy * vy + vz * vz);

  // Convert to mph
  return speedMS * 2.23694;
}

// ════════════════════════════════════════
// PEAK FORCES
// ════════════════════════════════════════
void computePeakForces() {
  for (int sensor = 0; sensor < 4; sensor++) {
    float maxForce = 0;
    for (int i = 0; i < sampleCount; i++) {
      float adc = (float)pressureBuf[i][sensor];
      if (adc > PRESSURE_ZERO_THRESH && adc < 4090) {
        // Convert ADC to conductance ratio: G_ratio = R_fixed / R_sensor
        // From voltage divider: ADC = 4095 * R_fixed / (R_sensor + R_fixed)
        // So: R_sensor = R_fixed * (4095/ADC - 1)
        // G_ratio = 1/R_sensor = ADC / (R_fixed * (4095 - ADC))
        // Force = G_ratio * R_fixed * calFactor = (ADC / (4095 - ADC)) * calFactor
        float conductance = adc / (4095.0 - adc);
        float force = conductance * calFactor[sensor];
        if (force > maxForce) maxForce = force;
      }
    }
    peakForceN[sensor] = maxForce;
  }
}

// ════════════════════════════════════════
// LIVE DATA (sent during IDLE for debugging)
// ════════════════════════════════════════
void sendLiveData() {
  int16_t pressure[4];
  pressure[0] = readPressureCh(0);
  pressure[1] = readPressureCh(1);
  pressure[2] = readPressureCh(2);
  pressure[3] = readPressureCh(3);

  int16_t accel[3], mag[3];
  readAccel(&accel[0], &accel[1], &accel[2]);
  readMag(&mag[0], &mag[1], &mag[2]);

  if (bleConnected) {
    pressureChar.writeValue((uint8_t*)pressure, 8);
    accelChar.writeValue((uint8_t*)accel, 6);
    magChar.writeValue((uint8_t*)mag, 6);
  }

  // Serial output
  Serial.print("P:");
  Serial.print(pressure[0]); Serial.print(",");
  Serial.print(pressure[1]); Serial.print(",");
  Serial.print(pressure[2]); Serial.print(",");
  Serial.print(pressure[3]);
  Serial.print(" A:");
  Serial.print(accel[0]); Serial.print(",");
  Serial.print(accel[1]); Serial.print(",");
  Serial.print(accel[2]);
  Serial.print(" M:");
  Serial.print(mag[0]); Serial.print(",");
  Serial.print(mag[1]); Serial.print(",");
  Serial.println(mag[2]);
}

// ════════════════════════════════════════
// SENSOR I/O
// ════════════════════════════════════════
// Pressure channels 0-3. On the custom board, channels 2/3 live on P0.04/P0.05
// which the XIAO variant doesn't expose as analog pins, so read them via mbed
// AnalogIn (16-bit, scaled down to match the 12-bit analogRead range).
int16_t readPressureCh(int ch) {
  switch (ch) {
    case 0: return analogRead(A0);  // P0.02 = AIN0 on both boards
    case 1: return analogRead(A1);  // P0.03 = AIN1 on both boards
#if CUSTOM_BOARD
    case 2: return ain2Raw.read_u16() >> 4;
    case 3: return ain3Raw.read_u16() >> 4;
#else
    case 2: return analogRead(A2);
    case 3: return analogRead(A3);
#endif
  }
  return 0;
}

void initSensors() {
  // H3LIS331DL
  writeReg(H3LIS_ADDR, 0x20, 0x3F); // Normal mode, 1000Hz, XYZ
  writeReg(H3LIS_ADDR, 0x23, 0x30); // ±400g

  uint8_t whoH = readReg(H3LIS_ADDR, 0x0F);
  Serial.print("H3LIS331DL WHO_AM_I: 0x");
  Serial.print(whoH, HEX);
  Serial.println(whoH == 0x32 ? " OK" : " ERROR");

  // LIS3MDL
  // FAST_ODR + medium-performance = 560Hz output. 80Hz UHP mode capped spin
  // measurement at 2400 RPM (Nyquist); real fastballs exceed that.
  writeReg(LIS3MDL_ADDR, 0x20, 0x22); // Medium perf XY, FAST_ODR → 560Hz
  writeReg(LIS3MDL_ADDR, 0x21, 0x00); // ±4 gauss
  writeReg(LIS3MDL_ADDR, 0x22, 0x00); // Continuous mode
  writeReg(LIS3MDL_ADDR, 0x23, 0x04); // Z-axis medium perf to match XY

  uint8_t whoM = readReg(LIS3MDL_ADDR, 0x0F);
  Serial.print("LIS3MDL WHO_AM_I: 0x");
  Serial.print(whoM, HEX);
  Serial.println(whoM == 0x3D ? " OK" : " ERROR");
}

void initBLE() {
  if (!BLE.begin()) {
    Serial.println("BLE init failed!");
    while (1);
  }

  BLE.setLocalName("SmartBall");
  BLE.setAdvertisedService(ballService);
  ballService.addCharacteristic(pressureChar);
  ballService.addCharacteristic(accelChar);
  ballService.addCharacteristic(magChar);
  ballService.addCharacteristic(metricsChar);
  BLE.addService(ballService);
  BLE.advertise();

  Serial.println("BLE advertising as 'SmartBall'");
}

void readAccel(int16_t* x, int16_t* y, int16_t* z) {
  I2C_BUS.beginTransmission(H3LIS_ADDR);
  I2C_BUS.write(0x28 | 0x80);
  I2C_BUS.endTransmission(false);
  I2C_BUS.requestFrom(H3LIS_ADDR, 6);
  *x = I2C_BUS.read() | (I2C_BUS.read() << 8);
  *y = I2C_BUS.read() | (I2C_BUS.read() << 8);
  *z = I2C_BUS.read() | (I2C_BUS.read() << 8);
}

void readMag(int16_t* x, int16_t* y, int16_t* z) {
  I2C_BUS.beginTransmission(LIS3MDL_ADDR);
  I2C_BUS.write(0x28 | 0x80);
  I2C_BUS.endTransmission(false);
  I2C_BUS.requestFrom(LIS3MDL_ADDR, 6);
  *x = I2C_BUS.read() | (I2C_BUS.read() << 8);
  *y = I2C_BUS.read() | (I2C_BUS.read() << 8);
  *z = I2C_BUS.read() | (I2C_BUS.read() << 8);
}

void writeReg(uint8_t addr, uint8_t reg, uint8_t val) {
  I2C_BUS.beginTransmission(addr);
  I2C_BUS.write(reg);
  I2C_BUS.write(val);
  I2C_BUS.endTransmission();
}

uint8_t readReg(uint8_t addr, uint8_t reg) {
  I2C_BUS.beginTransmission(addr);
  I2C_BUS.write(reg);
  I2C_BUS.endTransmission(false);
  I2C_BUS.requestFrom(addr, (uint8_t)1);
  return I2C_BUS.read();
}

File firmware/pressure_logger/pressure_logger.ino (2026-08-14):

/*
 * SmartBall — Pressure Logger Firmware (XIAO nRF52840)  [v2 HARNESS 2026-07-31]
 *
 * Samples 4x FlexiForce A301 at 120 Hz and streams each sample over BLE.
 * Pairs with analysis/ble_logger/ble_logger.py:
 *   Local name   : "SmartBall"
 *   Service UUID : 00001234-0000-1000-8000-00805f9b34fb
 *   Char UUID    : 00001235-0000-1000-8000-00805f9b34fb  (Read | Notify)
 *   Packet (12B) : uint32 t_ms + 4x uint16 raw ADC, little-endian,
 *                  channel order = sensors (S1, S2, S3, S4)
 *
 * Sensors sit at FIXED positions on the ball; which finger contacts which
 * sensor depends on the grip and is handled downstream (ble_logger.py asks
 * for the pitch type and tags every row). Physical wiring (v2 ferrule harness):
 *   S1 -> A0 (black),  S2 -> A1 (white),  S3 -> A2 (green),  S4 -> A3 (purple)
 * Adjacent pins are fine here: every connection is a housed female contact, so
 * there is no bare metal or flux on the pad row — that was v1's bridge mechanism.
 * Channel isolation is verified by isolation_test.ino, not by pin spacing.
 * PIN_ORDER below reads pins so the packet stays (S1, S2, S3, S4); per-sensor
 * calFactors (analysis/calibration/calfactors_v3.csv) are
 *   S1=BK 119, S2=RM 129, S3=KA 148, S4=CG 157.
 *
 * Raw ADC is streamed (no on-board force conversion); calibration is applied
 * in post-processing. 120 Hz sits under the measured ~151 Hz BLE notify
 * ceiling for clean, uniform delivery at throwing distance.
 */

#include <ArduinoBLE.h>

// Pins in packet-channel order: S1, S2, S3, S4
const int PIN_ORDER[4] = {A0, A1, A2, A3};

const uint32_t SAMPLE_HZ = 120;
const uint32_t SAMPLE_INTERVAL_US = 1000000UL / SAMPLE_HZ;  // 8333 us

BLEService ballService("00001234-0000-1000-8000-00805f9b34fb");
BLECharacteristic pressureChar("00001235-0000-1000-8000-00805f9b34fb",
                               BLERead | BLENotify, 12);
// Battery telemetry: uint16 millivolts, notified every 2 s. The CHG LED is
// buried once the ball is potted, so this is how charge state is verified
// through the sealed ball: on the charger the voltage climbs and holds
// ~4150-4200 mV; off the charger it slowly sags. Also a field battery gauge.
BLECharacteristic batteryChar("00001236-0000-1000-8000-00805f9b34fb",
                              BLERead | BLENotify, 2);

uint32_t lastSampleUs = 0;
uint32_t lastBattMs = 0;

uint16_t readBatteryMv() {
  // XIAO nRF52840: P0.31 reads VBAT through a 1M/510k divider that is only
  // connected while P0.14 is driven LOW. 12-bit ADC, 3.3 V full scale:
  // VBAT = adc/4095 * 3300 * (1510/510) mV. Divider tolerance ~±3% — read
  // the TREND (rising vs sagging), not the third digit.
  uint32_t adc = analogRead(P0_31);
  return (uint16_t)((unsigned long long)adc * 3300ULL * 1510ULL
                    / (4095ULL * 510ULL));
}

void setup() {
  Serial.begin(115200);           // debug only; ball runs on LiPo in the field
  analogReadResolution(12);       // 0..4095
  pinMode(P0_14, OUTPUT);         // VBAT_ENABLE: LOW connects the divider
  digitalWrite(P0_14, LOW);       // (~2 uA drain through 1.51M — negligible)

  if (!BLE.begin()) {
    while (1) { delay(1000); }    // BLE init failed — nothing useful to do
  }
  // Request a short connection interval (units of 1.25 ms: 6 = 7.5 ms,
  // 12 = 15 ms). Without this the central settles at ~20+ ms and only ~1
  // notification lands per connection event → ~48 Hz instead of 120 Hz.
  BLE.setConnectionInterval(6, 12);
  BLE.setLocalName("SmartBall");
  BLE.setDeviceName("SmartBall");
  BLE.setAdvertisedService(ballService);
  ballService.addCharacteristic(pressureChar);
  ballService.addCharacteristic(batteryChar);
  BLE.addService(ballService);
  BLE.advertise();
  Serial.println("SmartBall advertising (120 Hz pressure logger)");
}

void loop() {
  BLEDevice central = BLE.central();
  if (!central) return;

  Serial.print("Connected: ");
  Serial.println(central.address());
  lastSampleUs = micros();

  while (central.connected()) {
    uint32_t nowUs = micros();
    if ((uint32_t)(nowUs - lastSampleUs) < SAMPLE_INTERVAL_US) continue;
    lastSampleUs += SAMPLE_INTERVAL_US;   // fixed-rate, no drift accumulation

    // 12-byte packet: uint32 t_ms + 4x uint16 ADC (little-endian on Cortex-M4)
    uint8_t packet[12];
    uint32_t tMs = millis();
    memcpy(packet, &tMs, 4);
    for (int c = 0; c < 4; c++) {
      uint16_t adc = (uint16_t)analogRead(PIN_ORDER[c]);
      memcpy(packet + 4 + 2 * c, &adc, 2);
    }
    pressureChar.writeValue(packet, sizeof(packet));

    if (millis() - lastBattMs >= 2000) {
      lastBattMs = millis();
      uint16_t mv = readBatteryMv();
      batteryChar.writeValue((uint8_t *)&mv, 2);
    }
  }

  Serial.println("Disconnected — advertising again");
  BLE.advertise();
}

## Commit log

2026-08-14 Reproducibility materials for the instrumented baseball thesis
    Firmware, BLE acquisition client, per-sensor calibration, analysis pipeline,
    derived de-identified results, figures, hardware design files, and build
    documentation.
    Raw participant session captures are excluded per the participant-privacy
    commitments in the thesis; derived summary data sufficient to reproduce the
    reported figures and models are included.
    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
    [SmartBall_PCB.kicad_pcb, SmartBall_PCB.kicad_sch, calfactors_v3.csv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]
2026-08-14 Align Figure 6 caption with the release-time limitation
    The caption described the thumb as clearing 'before the fingers'. The finger
    markers in panel (b) sit at the pitch-window boundary rather than at an
    independently detected crossing, so the interval is now described as the
    thumb's lead on the end of ball contact.
    Also corrects the effort-only R-squared to 0.743 in the README, matching the
    refit value, and refreshes the bundled archive.

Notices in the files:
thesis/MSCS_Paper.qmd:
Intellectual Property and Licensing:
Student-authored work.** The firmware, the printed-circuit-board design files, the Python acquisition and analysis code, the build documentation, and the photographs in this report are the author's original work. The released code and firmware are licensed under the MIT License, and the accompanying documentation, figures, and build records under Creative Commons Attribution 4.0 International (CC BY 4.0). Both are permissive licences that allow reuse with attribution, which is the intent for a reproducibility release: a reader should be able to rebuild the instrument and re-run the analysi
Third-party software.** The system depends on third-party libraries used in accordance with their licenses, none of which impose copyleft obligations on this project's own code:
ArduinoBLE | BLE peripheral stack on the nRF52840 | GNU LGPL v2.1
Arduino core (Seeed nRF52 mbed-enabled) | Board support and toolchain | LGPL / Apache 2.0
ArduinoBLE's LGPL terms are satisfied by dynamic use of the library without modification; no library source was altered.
